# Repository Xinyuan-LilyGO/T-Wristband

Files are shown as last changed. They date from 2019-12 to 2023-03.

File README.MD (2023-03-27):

<h1 align = "center">🌟LilyGo T-Wristband🌟</h1>

**NOTE**

- [Better bracelet application from yacubovvs/CubOS](https://github.com/yacubovvs/CubOS)

- The new version screen (green label) requires configuration changes. [Refer to section 3 of this document for configuration](examples/T-Wristband-MPU9250/README.MD)

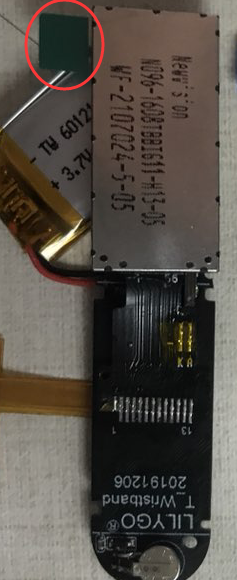
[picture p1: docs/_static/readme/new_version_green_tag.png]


- T-Wristband has two types of sensors, LSM9DS1 and MPU9250 sensors. How to distinguish the version you bought, please see the upper right part of the board below to distinguish

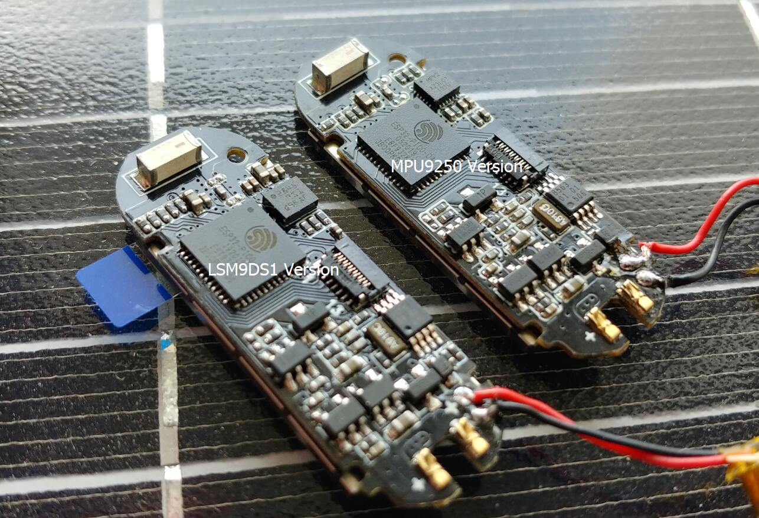
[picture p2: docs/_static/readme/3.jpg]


## Documentation

You can use the [T-Wristband Online Documentation](https://t-wristband-zh-cn.readthedocs.io/en/latest) to get all information about this project.

* [Getting Started](https://t-wristband-zh-cn.readthedocs.io/en/latest/get-started/index.html)
* [Hardware Reference](https://docs.espressif.com/projects/arduino-esp32/en/latest/installing.html)
* [Examples](https://t-wristband-zh-cn.readthedocs.io/en/latest/soft-reference/index.html)
* [Troubleshooting](https://t-wristband-zh-cn.readthedocs.io/en/latest/troubleshooting.html)
* [Copyrights](https://t-wristband-zh-cn.readthedocs.io/en/latest/COPYRIGHT.html)

## 📷 Product

| Examples | Product  Link | Schematic | Status |
| :---: | :---: | :---: | :----: |
| [LSM9DS1 Version](examples/T-Wristband-LSM9DS1/README_CN.md) | [AliExpress](https://www.aliexpress.com/item/4001162589218.html) | [Schematic](./schematic/T_Wristband_lsm9ds1_20200306.pdf) | ✅ |
| [MPU9250 Version](examples/T-Wristband-MPU9250/README_CN.md) | [AliExpress](https://www.aliexpress.com/item/4001162589218.html) | [Schematic](./schematic/T_Wristband_mpu9250.pdf) | ✅ |
| [MAX3010X](examples/T-Wristband-MAX3010X/README_CN.md) | [AliExpress](https://www.aliexpress.com/item/3256801677444772.html) | [Schematic](./schematic/T_Wristband_MAX30102.pdf) | ✅ |
| [DRV2605](examples/T-Wristband-DRV2605/README_CN.md) | [AliExpress](https://www.aliexpress.com/item/3256801703960897.html) | [Schematic](./schematic/T_Wristband_DRV2605.pdf) | ✅ |

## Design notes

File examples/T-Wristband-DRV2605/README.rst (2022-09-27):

*********
DRV2605
*********

.. note::

    Before using it, please install :ref:`Get Started <Install dependent libraries>`.

Introduction
=============

This document is `T-Wristband-DRV2605 <https://github.com/Xinyuan-LilyGO/LilyGo-T-Wristband/tree/master/examples/T-Wristband-DRV2605>`_ example description. DRV2605 Haptic Module for instructing the user how to use the ``T-Wristband``.

Arduino
========

``T-Wristband`` can choose ``ESP32 Dev Module``, and other settings can be kept as default.

.. warning::

    ``T-Wristband`` does not use PSRAM, please do not enable PSRAM, and call PSRAM functions.

For more DRV2605 examples, please refer to `Adafruit_DRV2605_Library <https://github.com/adafruit/Adafruit_DRV2605_Library>`_ .

Related Function Switch
========================

Some functions can be enabled or disabled by modifying the relevant macros in |l_github_Wristband-DRV2605.ino|_.

DRV2605 Haptic Module
----------------------

The ``ENABLE_DRV2605`` macro is used to enable the DRV2605 haptic module and is enabled by default.

.. literalinclude:: ../../../examples/T-Wristband-DRV2605/T-Wristband-DRV2605.ino
    :linenos:
    :language: c
    :lines: 13-13
    :lineno-start: 13

Hardware Test
---------------

The ``FACTORY_HW_TEST`` macro is used to test whether the hardware status of the bracelet is normal. It is disabled by default.

.. literalinclude:: ../../../examples/T-Wristband-DRV2605/T-Wristband-DRV2605.ino
    :linenos:
    :language: c
    :lines: 14-14
    :lineno-start: 14

OTA update
-----------

The ``ARDUINO_OTA_UPDATE`` macro is used to enable the OTA update function, which is disabled by default.

.. literalinclude:: ../../../examples/T-Wristband-DRV2605/T-Wristband-DRV2605.ino
    :linenos:
    :language: c
    :lines: 15-15
    :lineno-start: 15

.. _l_github_Wristband-DRV2605.ino: https://github.com/Xinyuan-LilyGO/LilyGo-T-Wristband/tree/master/examples/T-Wristband-DRV2605/T-Wristband-DRV2605.ino
.. |l_github_Wristband-DRV2605.ino| replace:: T-Wristband-DRV2605.ino

User Manual
============

OTA update:

    1. Touch and hold the button for three seconds to do a ``WiFi`` reset.
    #. Select ``T-Wristband`` in the ``Arduino IDE`` port to upgrade over the air, as shown below:

        

.. note::

    Enable ``ARDUINO_OTA_UPDATE`` macro OTA update is valid.

Datasheet
==========

* `ESP32-PICO-D4`_ (Datasheet)
* `ST7735`_ (Datasheet)
* `DRV2605`_ (Datasheet)

.. _ESP32-PICO-D4: https://www.espressif.com.cn/sites/default/files/documentation/esp32-pico-d4_datasheet_en.pdf
.. _ST7735: http://www.displayfuture.com/Display/datasheet/controller/ST7735.pdf
.. _DRV2605: https://www.ti.com/lit/ds/symlink/drv2605.pdf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

Pinout
===========

======== ====
Name     Pin
-------- ----
DRV_SDA  15
-------- ----
DRV_SCL  13
======== ====

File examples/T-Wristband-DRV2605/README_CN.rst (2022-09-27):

*********
DRV2605
*********

.. note::

    使用之前，请先安装 :ref:`快速开始 <安装依赖库>` 。

概况
======

本文档是 `T-Wristband-DRV2605 <https://github.com/Xinyuan-LilyGO/LilyGo-T-Wristband/tree/master/examples/T-Wristband-DRV2605>`_ 示例说明。用于指导用户如何使用 ``T-Wristband`` 的 DRV2605 触觉模块。

Arduino
========

板子可以选择 ``ESP32 Dev Module``，其他设置可以保持默认。

.. warning::

    ``T-Wristband`` 没有使用 PSRAM，请勿开启 PSRAM，和调用 PSRAM 的功能函数。

更多心率示例请参考 `Adafruit_DRV2605_Library <https://github.com/adafruit/Adafruit_DRV2605_Library>`_ 。

相关功能开关
============

通过修改 `T-Wristband-DRV2605.ino <https://github.com/Xinyuan-LilyGO/LilyGo-T-Wristband/tree/master/examples/T-Wristband-DRV2605/T-Wristband-DRV2605.ino>`_ 中的相关宏，使能或者失能某些功能。

DRV2605 触觉模块
----------------------

``ENABLE_DRV2605`` 宏用于使能 DRV2605 触觉模块，默认打开。

.. literalinclude:: ../../../examples/T-Wristband-DRV2605/T-Wristband-DRV2605.ino
    :linenos:
    :language: c
    :lines: 13-13
    :lineno-start: 13

测试手环的硬件状态是否正常
-----------------------------

``FACTORY_HW_TEST`` 宏用于测试手环的硬件状态是否正常，默认关闭。

.. literalinclude:: ../../../examples/T-Wristband-DRV2605/T-Wristband-DRV2605.ino
    :linenos:
    :language: c
    :lines: 14-14
    :lineno-start: 14

OTA 更新
---------

``ARDUINO_OTA_UPDATE`` 宏用于开启 OTA 更新功能，默认关闭。

.. literalinclude:: ../../../examples/T-Wristband-DRV2605/T-Wristband-DRV2605.ino
    :linenos:
    :language: c
    :lines: 15-15
    :lineno-start: 15

使用说明
=========

OTA 更新:

    1. 触摸按住按钮三秒钟，进行 ``WiFi`` 重置。
    #. 在 ``Arduino IDE`` 端口中选择 ``T-Wristband`` 进行空中升级，如下图：

        

.. note::

    使能 ``ARDUINO_OTA_UPDATE`` 宏 OTA 更新才有效。

数据手册
=========

* `ESP32-PICO-D4`_ (Datasheet)
* `ST7735`_ (Datasheet)
* `DRV2605`_ (Datasheet)

.. _ESP32-PICO-D4: https://www.espressif.com.cn/sites/default/files/documentation/esp32-pico-d4_datasheet_cn.pdf
.. _ST7735: http://www.displayfuture.com/Display/datasheet/controller/ST7735.pdf
.. _DRV2605: https://www.ti.com/lit/ds/symlink/drv2605.pdf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

引脚定义
========

======== ====
Name     Pin
-------- ----
DRV_SDA  15
-------- ----
DRV_SCL  13
======== ====

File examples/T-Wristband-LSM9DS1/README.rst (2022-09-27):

*********
LSM9DS1
*********

.. note::

    Before using it, please install :ref:`Get Started <Install dependent libraries>`.

Introduction
=============

This document is `T-Wristband-LSM9DS1 <https://github.com/Xinyuan-LilyGO/LilyGo-T-Wristband/tree/master/examples/T-Wristband-LSM9DS1>`_ example description. LSM9DS1 sensor for instructing the user how to use the ``T-Wristband``.

Arduino
========

``T-Wristband`` can choose ``ESP32 Dev Module``, and other settings can be kept as default.

.. warning::

    ``T-Wristband`` does not use PSRAM, please do not enable PSRAM, and call PSRAM functions.

Related Function Switch
========================

By modifying `T-Wristband-LSM9DS1.ino <https://github.com/Xinyuan-LilyGO/LilyGo-T-Wristband/tree/master/examples/T-Wristband-LSM9DS1/T-Wristband-LSM9DS1.ino>`_ The related macros in _ enable or disable certain functions.

Hardware Test
---------------

The ``FACTORY_HW_TEST`` macro is used to test whether the hardware status of the bracelet is normal. It is disabled by default.

.. literalinclude:: ../../../examples/T-Wristband-LSM9DS1/T-Wristband-LSM9DS1.ino
    :linenos:
    :language: c
    :lines: 14-14
    :lineno-start: 14

BLE transmits IMU data
-----------------------

The ``ENABLE_BLE_DATA_TRANSMISSION`` macro is used to test the BLE transfer IMU data example, which is disabled by default.

You can use ``nRF Connect``, ``LightBlue`` and other APPs to connect to view the data.

.. literalinclude:: ../../../examples/T-Wristband-LSM9DS1/T-Wristband-LSM9DS1.ino
    :linenos:
    :language: c
    :lines: 20-20
    :lineno-start: 20

Enable LSM9DS1 sensor function
-------------------------------

The ``ENABLE_SENSOR`` macro is used to enable the LSM9DS1 sensor function. Off by default.

.. literalinclude:: ../../../examples/T-Wristband-LSM9DS1/T-Wristband-LSM9DS1.ino
    :linenos:
    :language: c
    :lines: 23-23
    :lineno-start: 23

Enable LSM9DS1 sensor shutdown mode function
---------------------------------------------

The ``USE_PROTECTED_MEMBERS`` macro is used to enable the LSM9DS1 sensor shutdown mode function. Off by default.

.. literalinclude:: ../../../examples/T-Wristband-LSM9DS1/T-Wristband-LSM9DS1.ino
    :linenos:
    :language: c
    :lines: 37-37
    :lineno-start: 37

.. note::

    Before use, please make sure that you have changed the three member methods of SparkFun_LSM9DS1_Arduino_Library to common member methods, or directly use the library file in `libdeps`.

OTA update
-----------

The ``ARDUINO_OTA_UPDATE`` macro is used to enable the OTA update function, which is disabled by default.

.. literalinclude:: ../../../examples/T-Wristband-LSM9DS1/T-Wristband-LSM9DS1.ino
    :linenos:
    :language: c
    :lines: 17-17
    :lineno-start: 17

User Manual
============

Touch the button to switch to the next function when a press is detected:

    1. Press for the first time to view the nine-axis sensor information
    #. Press it a second time to enter deep sleep
    #. During deep sleep, touch again to wake up the bracelet

OTA update:

    1. Touch and hold the button for three seconds to do a ``WiFi`` reset.
    #. Select ``T-Wristband`` in the ``Arduino IDE`` port to upgrade over the air, as shown below:

        

.. note::

    Enable ``ARDUINO_OTA_UPDATE`` macro OTA update is valid.

Datasheet
==========

* `ESP32-PICO-D4`_ (Datasheet)
* `ST7735`_ (Datasheet)
* `LSM9DS1`_ (Datasheet)

.. _ESP32-PICO-D4: https://www.espressif.com.cn/sites/default/files/documentation/esp32-pico-d4_datasheet_en.pdf
.. _ST7735: http://www.displayfuture.com/Display/datasheet/controller/ST7735.pdf
.. _LSM9DS1: https://www.st.com/resource/en/datasheet/lsm9ds1.pdf

Pinout
===========

================== ======
Name               Pin
------------------ ------
TFT Driver         ST7735
TFT_MISO           N/A   
TFT_MOSI           19    
TFT_SCLK           18    
TFT_CS             5     
TFT_DC             23    
TFT_RST            26    
TFT_BL             27    
Touchpad           33    
Touchpad Power     25    
RTC Interrupt      34    
Battery ADC        35    
I2C_SDA            21    
I2C_SCL            22    
CHARGE Indication  32    
IMU INT1           38    
IMU INT2           39    
IMU INTM           37    
IMU RDY            36    
================== ======

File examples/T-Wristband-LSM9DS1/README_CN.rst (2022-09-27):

*********
LSM9DS1
*********

.. note::

    使用之前，请先安装 :ref:`快速开始 <安装依赖库>` 。

概况
======

本文档是 `T-Wristband-LSM9DS1 <https://github.com/Xinyuan-LilyGO/LilyGo-T-Wristband/tree/master/examples/T-Wristband-LSM9DS1>`_ 示例说明。用于指导用户如何使用 ``T-Wristband`` 的 LSM9DS1 传感器。

Arduino
========

板子可以选择 ``ESP32 Dev Module``，其他设置可以保持默认。

.. warning::

    ``T-Wristband`` 没有使用 PSRAM，请勿开启 PSRAM，和调用 PSRAM 的功能函数。

相关功能开关
============

通过修改 `T-Wristband-LSM9DS1.ino <https://github.com/Xinyuan-LilyGO/LilyGo-T-Wristband/tree/master/examples/T-Wristband-LSM9DS1/T-Wristband-LSM9DS1.ino>`_ 中的相关宏，使能或者失能某些功能。

测试手环的硬件状态是否正常
-----------------------------

``FACTORY_HW_TEST`` 宏用于测试手环的硬件状态是否正常，默认关闭。

.. literalinclude:: ../../../examples/T-Wristband-LSM9DS1/T-Wristband-LSM9DS1.ino
    :linenos:
    :language: c
    :lines: 14-14
    :lineno-start: 14

测试 BLE 传输 IMU 数据
-----------------------

``ENABLE_BLE_DATA_TRANSMISSION`` 宏用于测试BLE传输IMU数据示例，默认关闭。

可以使用 ``nRF Connect``， ``LightBlue`` 等 APP 进行连接查看数据。

.. literalinclude:: ../../../examples/T-Wristband-LSM9DS1/T-Wristband-LSM9DS1.ino
    :linenos:
    :language: c
    :lines: 20-20
    :lineno-start: 20

开启 LSM9DS1 传感器功能
-----------------------

``ENABLE_SENSOR`` 宏用于开启 LSM9DS1 传感器功能。默认关闭。

.. literalinclude:: ../../../examples/T-Wristband-LSM9DS1/T-Wristband-LSM9DS1.ino
    :linenos:
    :language: c
    :lines: 23-23
    :lineno-start: 23

开启 LSM9DS1 传感器关断模式功能
-------------------------------

``USE_PROTECTED_MEMBERS`` 宏用于开启 LSM9DS1 传感器关断模式功能。默认关闭。

.. literalinclude:: ../../../examples/T-Wristband-LSM9DS1/T-Wristband-LSM9DS1.ino
    :linenos:
    :language: c
    :lines: 37-37
    :lineno-start: 37

.. note::

    使用前请确保你已经将 SparkFun_LSM9DS1_Arduino_Library 三个成员方法更改为共有成员方法，或者直接使用 `libdeps` 内的库文件。

OTA 更新
---------

``ARDUINO_OTA_UPDATE`` 宏用于开启 OTA 更新功能，默认关闭。

.. literalinclude:: ../../../examples/T-Wristband-LSM9DS1/T-Wristband-LSM9DS1.ino
    :linenos:
    :language: c
    :lines: 17-17
    :lineno-start: 17

使用说明
=========

触摸按钮当检测到按下则切换功能:

    1. 按下第一次 将查看九轴传感器信息
    #. 按下第二次 将进入深度睡眠
    #. 在深度睡眠中，再次触摸唤醒手环

OTA 更新:

    1. 触摸按住按钮三秒钟，进行 ``WiFi`` 重置。
    #. 在 ``Arduino IDE`` 端口中选择 ``T-Wristband`` 进行空中升级，如下图：

        

.. note::

    使能 ``ARDUINO_OTA_UPDATE`` 宏 OTA 更新才有效。

数据手册
=========

* `ESP32-PICO-D4`_ (Datasheet)
* `ST7735`_ (Datasheet)
* `LSM9DS1`_ (Datasheet)

.. _ESP32-PICO-D4: https://www.espressif.com.cn/sites/default/files/documentation/esp32-pico-d4_datasheet_cn.pdf
.. _ST7735: http://www.displayfuture.com/Display/datasheet/controller/ST7735.pdf
.. _LSM9DS1: https://www.st.com/resource/en/datasheet/lsm9ds1.pdf

引脚定义
========

================== ======
Name               Pin
------------------ ------
TFT Driver         ST7735
TFT_MISO           N/A   
TFT_MOSI           19    
TFT_SCLK           18    
TFT_CS             5     
TFT_DC             23    
TFT_RST            26    
TFT_BL             27    
Touchpad           33    
Touchpad Power     25    
RTC Interrupt      34    
Battery ADC        35    
I2C_SDA            21    
I2C_SCL            22    
CHARGE Indication  32    
IMU INT1           38    
IMU INT2           39    
IMU INTM           37    
IMU RDY            36    
================== ======

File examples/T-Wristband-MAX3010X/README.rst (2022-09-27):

*********
MAX3010X
*********

.. note::

    Before using it, please install :ref:`Get Started <Install dependent libraries>`.

Introduction
=============

This document is `T-Wristband-MAX3010X <https://github.com/Xinyuan-LilyGO/LilyGo-T-Wristband/tree/master/examples/T-Wristband-MAX3010X>`_ example description. A MAX3010X sensor for instructing the user on how to use the ``T-Wristband``.

Arduino
========

``T-Wristband`` can choose ``ESP32 Dev Module``, and other settings can be kept as default.

For more heart rate examples, please refer to `SparkFun_MAX3010x_Sensor_Library <https://github.com/sparkfun/SparkFun_MAX3010x_Sensor_Library>`_ .

.. warning::

    ``T-Wristband`` does not use PSRAM, please do not enable PSRAM, and call PSRAM functions.

Datasheet
==========

* `ESP32-PICO-D4`_ (Datasheet)
* `ST7735`_ (Datasheet)
* `MAX30102`_ (Datasheet)

.. _ESP32-PICO-D4: https://www.espressif.com.cn/sites/default/files/documentation/esp32-pico-d4_datasheet_en.pdf
.. _ST7735: http://www.displayfuture.com/Display/datasheet/controller/ST7735.pdf
.. _MAX30102: https://datasheets.maximintegrated.com/en/ds/MAX30102.pdf

Pinout
===========

============= ====
Name          Pin
------------- ----
MAX3010X_SDA  15
------------- ----
MAX3010X_SCL  13
------------- ----
MAX3010X_IRQ  4
============= ====

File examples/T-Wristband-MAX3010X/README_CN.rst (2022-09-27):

*********
MAX3010X
*********

.. note::

    使用之前，请先安装 :ref:`快速开始 <安装依赖库>` 。

概况
======

本文档是 `T-Wristband-MAX3010X <https://github.com/Xinyuan-LilyGO/LilyGo-T-Wristband/tree/master/examples/T-Wristband-MAX3010X>`_ 示例说明。用于指导用户如何使用 ``T-Wristband`` 的 MAX3010X 传感器。

Arduino
========

板子可以选择 ``ESP32 Dev Module``，其他设置可以保持默认。

.. warning::

    ``T-Wristband`` 没有使用 PSRAM，请勿开启 PSRAM，和调用 PSRAM 的功能函数。

更多心率示例请参考 `SparkFun_MAX3010x_Sensor_Library <https://github.com/sparkfun/SparkFun_MAX3010x_Sensor_Library>`_ 。

数据手册
=========

* `ESP32-PICO-D4`_ (Datasheet)
* `ST7735`_ (Datasheet)
* `MAX30102`_ (Datasheet)

.. _ESP32-PICO-D4: https://www.espressif.com.cn/sites/default/files/documentation/esp32-pico-d4_datasheet_cn.pdf
.. _ST7735: http://www.displayfuture.com/Display/datasheet/controller/ST7735.pdf
.. _MAX30102: https://datasheets.maximintegrated.com/en/ds/MAX30102.pdf

引脚定义
========

============= ====
Name          Pin
------------- ----
MAX3010X_SDA  15
------------- ----
MAX3010X_SCL  13
------------- ----
MAX3010X_IRQ  4
============= ====

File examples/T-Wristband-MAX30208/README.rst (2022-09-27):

*********
MAX30208
*********

.. note::

    Before using it, please install :ref:`Get Started <Install dependent libraries>`.

Introduction
=============

This document is a `T-Wristband-MAX30208 <https://github.com/Xinyuan-LilyGO/LilyGo-T-Wristband/tree/master/examples/T-Wristband-MAX30208>`_ example description. A MAX30208 sensor for instructing the user on how to use the ``T-Wristband``.

Arduino
========

``T-Wristband`` can choose ``ESP32 Dev Module``, and other settings can be kept as default.

.. warning::

    ``T-Wristband`` does not use PSRAM, please do not enable PSRAM, and call PSRAM functions.

Related Function Switch
========================

By modifying `T-Wristband-MAX30208.ino <https://github.com/Xinyuan-LilyGO/LilyGo-T-Wristband/tree/master/examples/T-Wristband-MAX30208/T-Wristband-MAX30208.ino>`_ The related macros in _ enable or disable certain functions.

Hardware Test
---------------

The ``FACTORY_HW_TEST`` macro is used to test whether the hardware status of the bracelet is normal. It is disabled by default.

.. literalinclude:: ../../../examples/T-Wristband-MAX30208/T-Wristband-MAX30208.ino
    :linenos:
    :language: c
    :lines: 16-16
    :lineno-start: 16

OTA update
-----------

The ``ARDUINO_OTA_UPDATE`` macro is used to enable the OTA update function, which is disabled by default.

.. literalinclude:: ../../../examples/T-Wristband-MAX30208/T-Wristband-MAX30208.ino
    :linenos:
    :language: c
    :lines: 17-17
    :lineno-start: 17

.. _l_github_Wristband-MPU9250.ino: https://github.com/Xinyuan-LilyGO/LilyGo-T-Wristband/tree/master/examples/T-Wristband-MAX30208/T-Wristband-MAX30208.ino
.. |l_github_Wristband-MPU9250.ino| replace:: T-Wristband-MAX30208.ino

User Manual
============

OTA update:

    1. Touch and hold the button for three seconds to do a ``WiFi`` reset.
    #. Select ``T-Wristband`` in the ``Arduino IDE`` port to upgrade over the air, as shown below:

        

.. note::

    Enable ``ARDUINO_OTA_UPDATE`` macro OTA update is valid.

Datasheet
==========

* `ESP32-PICO-D4`_ (Datasheet)
* `ST7735`_ (Datasheet)
* `MAX30208`_ (Datasheet)

.. _ESP32-PICO-D4: https://www.espressif.com.cn/sites/default/files/documentation/esp32-pico-d4_datasheet_en.pdf
.. _ST7735: http://www.displayfuture.com/Display/datasheet/controller/ST7735.pdf
.. _MAX30208: https://datasheets.maximintegrated.com/en/ds/MAX30208.pdf

Pinout
===========

======== ====
Name     Pin
-------- ----
DRV_SDA  15
-------- ----
DRV_SCL  13
======== ====

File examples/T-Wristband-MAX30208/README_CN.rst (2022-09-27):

*********
MAX30208
*********

.. note::

    使用之前，请先安装 :ref:`快速开始 <安装依赖库>` 。

概况
======

本文档是 `T-Wristband-MAX30208 <https://github.com/Xinyuan-LilyGO/LilyGo-T-Wristband/tree/master/examples/T-Wristband-MAX30208>`_ 示例说明。用于指导用户如何使用 ``T-Wristband`` 的 MAX30208 传感器。

Arduino
========

板子可以选择 ``ESP32 Dev Module``，其他设置可以保持默认。

.. warning::

    ``T-Wristband`` 没有使用 PSRAM，请勿开启 PSRAM，和调用 PSRAM 的功能函数。

相关功能开关
============

通过修改 `T-Wristband-MAX30208.ino <https://github.com/Xinyuan-LilyGO/LilyGo-T-Wristband/tree/master/examples/T-Wristband-MAX30208/T-Wristband-MAX30208.ino>`_ 中的相关宏，使能或者失能某些功能。

测试手环的硬件状态是否正常
--------------------------

``FACTORY_HW_TEST`` 宏用于测试手环的硬件状态是否正常，默认关闭。

.. literalinclude:: ../../../examples/T-Wristband-MAX30208/T-Wristband-MAX30208.ino
    :linenos:
    :language: c
    :lines: 16-16
    :lineno-start: 16

启用 OTA 更新
--------------

``ARDUINO_OTA_UPDATE`` 宏用于开启 OTA 更新功能，默认关闭。

.. literalinclude:: ../../../examples/T-Wristband-MAX30208/T-Wristband-MAX30208.ino
    :linenos:
    :language: c
    :lines: 17-17
    :lineno-start: 17

.. _l_github_Wristband-MPU9250.ino: https://github.com/Xinyuan-LilyGO/LilyGo-T-Wristband/tree/master/examples/T-Wristband-MAX30208/T-Wristband-MAX30208.ino
.. |l_github_Wristband-MPU9250.ino| replace:: T-Wristband-MAX30208.ino

使用说明
=========

OTA 更新:

    1. 触摸按住按钮三秒钟，进行 ``WiFi`` 重置。
    #. 在 ``Arduino IDE`` 端口中选择 ``T-Wristband`` 进行空中升级，如下图：

        

.. note::

    使能 ``ARDUINO_OTA_UPDATE`` 宏 OTA 更新才有效。

数据手册
=========

* `ESP32-PICO-D4`_ (Datasheet)
* `ST7735`_ (Datasheet)
* `MAX30208`_ (Datasheet)

.. _ESP32-PICO-D4: https://www.espressif.com.cn/sites/default/files/documentation/esp32-pico-d4_datasheet_cn.pdf
.. _ST7735: http://www.displayfuture.com/Display/datasheet/controller/ST7735.pdf
.. _MAX30208: https://datasheets.maximintegrated.com/en/ds/MAX30208.pdf

引脚定义
========

======== ====
Name     Pin
-------- ----
DRV_SDA  15
-------- ----
DRV_SCL  13
======== ====

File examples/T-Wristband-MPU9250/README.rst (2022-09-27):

*********
MPU9250
*********

.. note::

    Before using it, please install :ref:`Get Started <Install dependent libraries>`.

Introduction
=============

This document is `T-Wristband-MPU9250 <https://github.com/Xinyuan-LilyGO/LilyGo-T-Wristband/tree/master/examples/T-Wristband-MPU9250>`_ example description. MPU9250 sensor for instructing the user how to use the ``T-Wristband``.

Arduino
========

``T-Wristband`` can choose ``ESP32 Dev Module``, and other settings can be kept as default.

.. warning::

    ``T-Wristband`` does not use PSRAM, please do not enable PSRAM, and call PSRAM functions.

Related Function Switch
========================

Enable or disable certain functions by modifying the relevant macros in |l_github_Wristband-MPU9250.ino|_.

Hardware Test
---------------

The ``FACTORY_HW_TEST`` macro is used to test whether the hardware status of the bracelet is normal. It is disabled by default.

.. literalinclude:: ../../../examples/T-Wristband-MPU9250/T-Wristband-MPU9250.ino
    :linenos:
    :language: c
    :lines: 14-14
    :lineno-start: 14

OTA update
-----------

The ``ARDUINO_OTA_UPDATE`` macro is used to enable the OTA update function, which is disabled by default.

.. literalinclude:: ../../../examples/T-Wristband-MPU9250/T-Wristband-MPU9250.ino
    :linenos:
    :language: c
    :lines: 17-17
    :lineno-start: 17

.. _l_github_Wristband-MPU9250.ino: https://github.com/Xinyuan-LilyGO/LilyGo-T-Wristband/tree/master/examples/T-Wristband-MPU9250/T-Wristband-MPU9250.ino
.. |l_github_Wristband-MPU9250.ino| replace:: T-Wristband-MPU9250.ino

User Manual
============

Touch the button to switch to the next function when a press is detected:

    1. Press for the first time to view the nine-axis sensor information
    #. Press it a second time to enter deep sleep
    #. During deep sleep, touch again to wake up the bracelet

OTA update:

    1. Touch and hold the button for three seconds to do a ``WiFi`` reset.
    #. Select ``T-Wristband`` in the ``Arduino IDE`` port to upgrade over the air, as shown below:

        

.. note::

    Enable ``ARDUINO_OTA_UPDATE`` macro OTA update is valid.

Datasheet
==========

* `ESP32-PICO-D4`_ (Datasheet)
* `ST7735`_ (Datasheet)
* `MPU9250`_ (Datasheet)

.. _ESP32-PICO-D4: https://www.espressif.com.cn/sites/default/files/documentation/esp32-pico-d4_datasheet_en.pdf
.. _ST7735: http://www.displayfuture.com/Display/datasheet/controller/ST7735.pdf
.. _MPU9250: https://invensense.tdk.com/wp-content/uploads/2015/02/PS-MPU-9250A-01-v1.1.pdf

Pinout
===========

================== =======
Name               Pin
------------------ -------
TFT Driver         ST7735
TFT_MISO           N/A
TFT_MOSI           19
TFT_SCLK           18
TFT_CS             5
TFT_DC             23
TFT_RST            26
TFT_BL             27
Touchpad           33
Touchpad Power     25
IMU Interrupt      38
RTC Interrupt      34
Battery ADC        35
VBUS ADC           36
I2C SDA            21
I2C SCL            22
LED and Vibration  4
CHARGE Indication  38
================== =======

.. note::

    The vibration module is driven using IO4, which is incorporated with the LED.

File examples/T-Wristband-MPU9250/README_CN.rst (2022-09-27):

*********
MPU9250
*********

.. note::

    使用之前，请先安装 :ref:`快速开始 <安装依赖库>` 。

概况
======

本文档是 `T-Wristband-MPU9250 <https://github.com/Xinyuan-LilyGO/LilyGo-T-Wristband/tree/master/examples/T-Wristband-MPU9250>`_ 示例说明。用于指导用户如何使用 ``T-Wristband`` 的 MPU9250 传感器。

Arduino
========

板子可以选择 ``ESP32 Dev Module``，其他设置可以保持默认。

.. warning::

    ``T-Wristband`` 没有使用 PSRAM，请勿开启 PSRAM，和调用 PSRAM 的功能函数。

相关功能开关
============

通过修改 |l_github_Wristband-MPU9250.ino|_ 中的相关宏，使能或者失能某些功能。

测试手环的硬件状态是否正常
--------------------------

``FACTORY_HW_TEST`` 宏用于测试手环的硬件状态是否正常，默认关闭。

.. literalinclude:: ../../../examples/T-Wristband-MPU9250/T-Wristband-MPU9250.ino
    :linenos:
    :language: c
    :lines: 14-14
    :lineno-start: 14

启用 OTA 更新
--------------

``ARDUINO_OTA_UPDATE`` 宏用于开启 OTA 更新功能，默认关闭。

.. literalinclude:: ../../../examples/T-Wristband-MPU9250/T-Wristband-MPU9250.ino
    :linenos:
    :language: c
    :lines: 17-17
    :lineno-start: 17

.. _l_github_Wristband-MPU9250.ino: https://github.com/Xinyuan-LilyGO/LilyGo-T-Wristband/tree/master/examples/T-Wristband-MPU9250/T-Wristband-MPU9250.ino
.. |l_github_Wristband-MPU9250.ino| replace:: T-Wristband-MPU9250.ino

使用说明
=========

触摸按钮当检测到按下则切换功能:

    1. 按下第一次 将查看九轴传感器信息
    #. 按下第二次 将进入深度睡眠
    #. 在深度睡眠中，再次触摸唤醒手环

OTA 更新:

    1. 触摸按住按钮三秒钟，进行 ``WiFi`` 重置。
    #. 在 ``Arduino IDE`` 端口中选择 ``T-Wristband`` 进行空中升级，如下图：

        

.. note::

    使能 ``ARDUINO_OTA_UPDATE`` 宏 OTA 更新才有效。

数据手册
=========

* `ESP32-PICO-D4`_ (Datasheet)
* `ST7735`_ (Datasheet)
* `MPU9250`_ (Datasheet)

.. _ESP32-PICO-D4: https://www.espressif.com.cn/sites/default/files/documentation/esp32-pico-d4_datasheet_cn.pdf
.. _ST7735: http://www.displayfuture.com/Display/datasheet/controller/ST7735.pdf
.. _MPU9250: https://invensense.tdk.com/wp-content/uploads/2015/02/PS-MPU-9250A-01-v1.1.pdf

引脚定义
========

================== =======
Name               Pin
------------------ -------
TFT Driver         ST7735
TFT_MISO           N/A
TFT_MOSI           19
TFT_SCLK           18
TFT_CS             5
TFT_DC             23
TFT_RST            26
TFT_BL             27
Touchpad           33
Touchpad Power     25
IMU Interrupt      38
RTC Interrupt      34
Battery ADC        35
VBUS ADC           36
I2C SDA            21
I2C SCL            22
LED and Vibration  4
CHARGE Indication  38
================== =======

.. note::

    振动模块使用IO4进行驱动，与 LED 合并在一起。

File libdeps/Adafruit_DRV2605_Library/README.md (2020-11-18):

# Adafruit DRV2605 Library 

This is a library for the Adafruit DRV2605L Haptic Driver ----> http://www.adafruit.com/products/2305

Check out the links above for our tutorials and wiring diagrams.

This motor/haptic driver uses I2C to communicate.

Adafruit invests time and resources providing this open source code,
please support Adafruit and open-source hardware by purchasing
products from Adafruit!

Written by Limor Fried/Ladyada for Adafruit Industries.

MIT license, all text above must be included in any redistribution.

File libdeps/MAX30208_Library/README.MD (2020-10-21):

MAX30208 Sensor Library
=====================

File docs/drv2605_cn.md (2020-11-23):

## **[English](../examples/T-Wristband-DRV2605/README.MD) | 中文**

## 使用之前,请阅读下面的描述

1. 根据你使用的串口通讯板安装对应的驱动程序
   - [CP21xx Drivers](https://www.silabs.com/products/development-tools/software/usb-to-uart-bridge-vcp-drivers)
   - [CH340 Drivers](http://www.wch-ic.com/search?q=ch340&t=downloads)

2. 安装下面列表中的依赖库,默认已将所需要的库文件放置在`libdeps`目录中,请将`libdeps`目录内所有文件拷贝到`C:\<UserName>\Documents\Arduino\libraries`目录内
   - [TFT_eSPI](https://github.com/Bodmer/TFT_eSPI)
   - [Adafruit_DRV2605_Library](https://github.com/adafruit/Adafruit_DRV2605_Library)

3. 配置TFT头文件(**如果使用`libdeps`目录中库文件,可以跳过这一步**)
    - 在你的库文件夹目录中找到**TFT_eSPI**目录
    - 在**TFT_eSPI**根目录中找到`User_Setup_Select.h`并且打开进行编辑
    - 将 文件头部`#include <User_Setup.h>` 注释掉
    - 找到 `#include <User_Setups/Setup26_TTGO_T_Wristband.h>`,取消前面的注释,保存退出
    - 最终效果如下图:
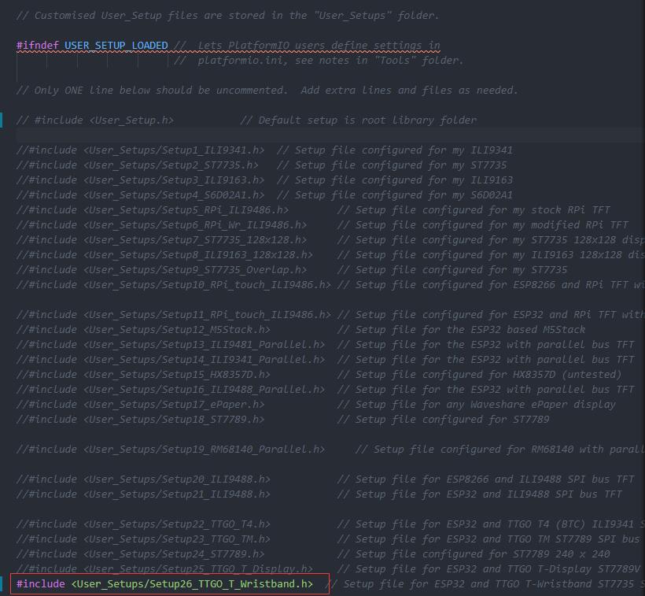
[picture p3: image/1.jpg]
        
4. 板子可以选择**ESP32 Dev Module**，其他设置可以保持默认,注意 `T-Wristband` 没有使用PSRAM,请勿开启PSRAM,和调用PSRAM的功能函数

5. 更多心率示例请参考`Adafruit_DRV2605_Library`

## 数据手册
- [DRV2605](https://www.ti.com/product/DRV2605)
- [ST7735](http://www.displayfuture.com/Display/datasheet/controller/ST7735.pdf)
- [ESP32-PICO-D4](https://www.espressif.com/sites/default/files/documentation/esp32-pico-d4_datasheet_en.pdf)

## 引脚定义
| Name | Pin |
| --- | --- |
| DRV_SDA | 15  |
| DRV_SCL | 13  |

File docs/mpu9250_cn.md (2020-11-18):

## **[English](../examples/T-Wristband-MPU9250/README.MD) | 中文**

## 使用之前,请阅读下面的描述

1. 根据你使用的串口通讯板安装对应的驱动程序
   - [CP21xx Drivers](https://www.silabs.com/products/development-tools/software/usb-to-uart-bridge-vcp-drivers)
   - [CH340 Drivers](http://www.wch-ic.com/search?q=ch340&t=downloads)

2. 安装下面列表中的依赖库,默认已将所需要的库文件放置在`libdeps`目录中,请将`libdeps`目录内所有文件拷贝到`C:\<UserName>\Documents\Arduino\libraries`目录内
   - [TFT_eSPI](https://github.com/Bodmer/TFT_eSPI)
   - [PCF8563_Library](https://github.com/lewisxhe/PCF8563_Library)

3. 配置TFT头文件(**如果使用`libdeps`目录中库文件,可以跳过这一步**)
    - 在你的库文件夹目录中找到**TFT_eSPI**目录
    - 在**TFT_eSPI**根目录中找到`User_Setup_Select.h`并且打开进行编辑
    - 将 文件头部`#include <User_Setup.h>` 注释掉
    - 找到 `#include <User_Setups/Setup26_TTGO_T_Wristband.h>`,取消前面的注释,保存退出
    - 最终效果如下图:
        
4. 板子可以选择**ESP32 Dev Module**，其他设置可以保持默认,注意 `T-Wristband` 没有使用PSRAM,请勿开启PSRAM,和调用PSRAM的功能函数

5. `ARDUINO_OTA_UPDATE` 宏用于**WiFiManager**和**OTA更新**,默认为关闭,如需开启请在`sketch`中开启
    - 当`ARDUINO_OTA_UPDATE`开启后,触摸按住按钮三秒钟进行`WiFi`重置
    - 开启OTA更新后,你可以在Arduino IDE端口中选择 `T-Wristband` 进行空中升级,如下图
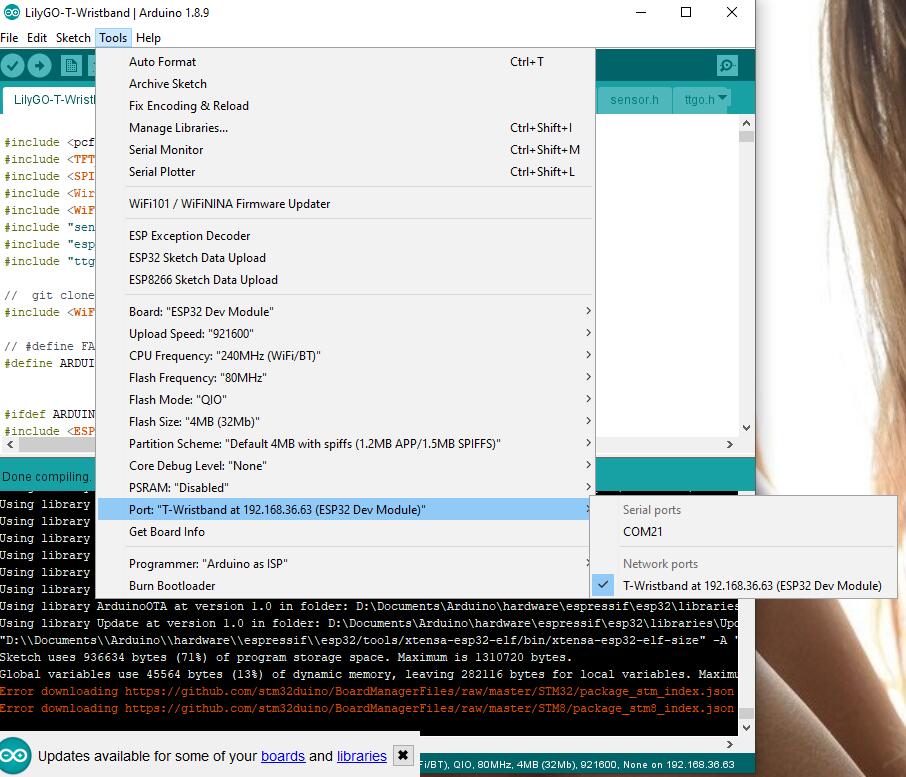
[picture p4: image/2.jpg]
        

6. `FACTORY_HW_TEST` 宏用于测试手环的硬件状态是否正常,默认关闭,如需开启请在`sketch`中开启
7. 触摸按钮当检测到按下则切换下一个功能
    - 按下第一次 将查看九轴传感器信息
    - 按下第二次 将进入深度睡眠
    - 在深度睡眠中,再次触碰 将唤醒手环

## 数据手册
- [MPU9250 Sensor](https://invensense.tdk.com/wp-content/uploads/2015/02/PS-MPU-9250A-01-v1.1.pdf)
- [ST7735](http://www.displayfuture.com/Display/datasheet/controller/ST7735.pdf)
- [ESP32-PICO-D4](https://www.espressif.com/sites/default/files/documentation/esp32-pico-d4_datasheet_en.pdf)
- [DRV2605](https://www.ti.com/product/DRV2605)
- 
## 引脚定义
| Name | Pin |
| --- | --- |
| TFT Driver | ST7735 |
| TFT_MISO | N/A |
| TFT_MOSI | 19 |
| TFT_SCLK | 18 |
| TFT_CS | 5 |
| TFT_DC | 23 |
| TFT_RST | 26 |
| TFT_BL | 27 |
| Touchpad | 33 |
| Touchpad Power | 25 |
| IMU Interrupt | 38 |
| RTC Interrupt | 34 |
| Battery ADC | 35 |
| VBUS ADC | 36 |
| I2C SDA | 21 |
| I2C SCL | 22 |
| LED and Vibration | 4 |
| CHARGE Indication | 38 |

- 振动模块 使用IO4进行驱动，与LED合并在一起

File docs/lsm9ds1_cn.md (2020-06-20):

## **[English](../examples/T-Wristband-LSM9DS1/README.MD) | 中文**

## 使用之前,请阅读下面的描述

1. 根据你使用的串口通讯板安装对应的驱动程序
   - [CP21xx Drivers](https://www.silabs.com/products/development-tools/software/usb-to-uart-bridge-vcp-drivers)
   - [CH340 Drivers](http://www.wch-ic.com/search?q=ch340&t=downloads)

2. 安装下面列表中的依赖库,默认已将所需要的库文件放置在`libdeps`目录中,请将`libdeps`目录内所有文件拷贝到`C:\<UserName>\Documents\Arduino\libraries`目录内
   - [TFT_eSPI](https://github.com/Bodmer/TFT_eSPI)
   - [PCF8563_Library](https://github.com/lewisxhe/PCF8563_Library)
   - [WiFiManager for esp32](https://github.com/tzapu/WiFiManager)
   - [SparkFun_LSM9DS1_Arduino_Library](https://github.com/sparkfun/SparkFun_LSM9DS1_Arduino_Library)

3. 配置TFT头文件(**如果使用`libdeps`目录中库文件,可以跳过这一步**)
    - 在你的库文件夹目录中找到**TFT_eSPI**目录
    - 在**TFT_eSPI**根目录中找到`User_Setup_Select.h`并且打开进行编辑
    - 将 文件头部`#include <User_Setup.h>` 注释掉
    - 找到 `#include <User_Setups/Setup26_TTGO_T_Wristband.h>`,取消前面的注释,保存退出
    - 最终效果如下图:
        
4. 板子可以选择**ESP32 Dev Module**，其他设置可以保持默认,注意 `T-Wristband` 没有使用PSRAM,请勿开启PSRAM,和调用PSRAM的功能函数

5. `ARDUINO_OTA_UPDATE` 宏用于**WiFiManager**和**OTA更新**,默认为关闭,如需开启请在`sketch`中开启
    - 当`ARDUINO_OTA_UPDATE`开启后,触摸按住按钮三秒钟进行`WiFi`重置
    - 开启OTA更新后,你可以在Arduino IDE端口中选择 `T-Wristband` 进行空中升级,如下图
        

6. `FACTORY_HW_TEST` 宏用于测试手环的硬件状态是否正常,默认关闭,如需开启请在`sketch`中开启
7. 触摸按钮当检测到按下则切换下一个功能
    - 按下第一次 将查看九轴传感器信息
    - 按下第二次 将进入深度睡眠
    - 在深度睡眠中,再次触碰 将唤醒手环

8. `ENABLE_BLE_DATA_TRANSMISSION` 宏用于测试BLE传输IMU数据示例 ,默认关闭, 可以使用`nRF Connect` , `LightBlue` 等APP 进行连接查看数据

9. `ENABLE_SENSOR`宏用于开启LSM9DS1传感器功能.默认关闭

10. `USE_PROTECTED_MEMBERS`宏用于开启LSM9DS1传感器关断模式功能.默认关闭,使用前请确保你已经将SparkFun_LSM9DS1_Arduino_Library 三个成员方法更改为共有成员方法，或者直接使用`libdeps`内的库文件

## 数据手册
- [lsm9ds1 Sensor](https://www.st.com/resource/en/datasheet/lsm9ds1.pdf)
- [ST7735](http://www.displayfuture.com/Display/datasheet/controller/ST7735.pdf)
- [ESP32-PICO-D4](https://www.espressif.com/sites/default/files/documentation/esp32-pico-d4_datasheet_en.pdf)

## 引脚定义
| Name | Pin |
| --- | --- |
| TFT Driver | ST7735 |
| TFT_MISO | N/A |
| TFT_MOSI | 19 |
| TFT_SCLK | 18 |
| TFT_CS | 5 |
| TFT_DC | 23 |
| TFT_RST | 26 |
| TFT_BL | 27 |
| Touchpad | 33 |
| Touchpad Power | 25 |
| RTC Interrupt | 34 |
| Battery ADC | 35 |
| I2C_SDA | 21 |
| I2C_SCL | 22 |
| CHARGE Indication | 32 |
| IMU INT1 | 38 |
| IMU INT2 | 39 |
| IMU INTM | 37 |
| IMU RDY | 36 |

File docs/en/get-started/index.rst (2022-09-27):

************
Get Started
************

This document is intended to guide users to build a software environment for T-Wristband hardware development.

Introduction
=============

T-Wristband supports the following features:

    * ESP32-PICO-D4
    * 9-axis Digital Motion Processor(PMU9250 or LSM9DS1)
    * PCF8563 Real-Time Clock
    * 0.96-inch IPS(80 * 160)
    * 120mAh Rechargeable Lithium Battery
    * TP4054 Battery Charging Chip
    * TTP223 Touch Button
    * MAX30102(optional)
    * DRV2605(optional)

What You Need
==============

Hardware:

* T-Wristband
* Programmer
* Computer running Windows, Linux, or macOS

Software:

* arduino
* platformio

.. todo: 开发板简介

Install prerequisites
======================

Please complete the installation of the tool first. The specific steps are as follows:

+-------------------+-------------------+
|     |  |
+-------------------+-------------------+
| `arduino`_        | `platformio`_     |
+-------------------+-------------------+





.. _arduino: https://docs.espressif.com/projects/arduino-esp32/en/latest/installing.html#installing-using-arduino-ide
.. _platformio: https://docs.espressif.com/projects/arduino-esp32/en/latest/installing.html#installing-using-platformio

Install serial driver
======================

Due to the shortage of chips and the price increase, T-Wristband's programmer has used cp21xx or ch340. You need to install the corresponding driver according to different Programmers.

* `CP21xx Drivers`_
* `CH340 Drivers`_

.. _CP21xx Drivers: https://www.silabs.com/products/development-tools/software/usb-to-uart-bridge-vcp-drivers
.. _CH340 Drivers: http://www.wch-ic.com/search?q=ch340&t=downloads

.. _Install dependent libraries:

Install dependent libraries
============================

T-Wristband requires the following dependency library support, users can use the library to manage the installation.

* `TFT_eSPI`_
* `PCF8563_Library`_
* `WiFiManager for esp32`_
* `SparkFun_LSM9DS1_Arduino_Library`_
* `Adafruit_DRV2605_Library`_
* `SparkFun_MAX3010x_Sensor_Library`_

.. _TFT_eSPI: https://github.com/Bodmer/TFT_eSPI
.. _PCF8563_Library: https://github.com/lewisxhe/PCF8563_Library
.. _WiFiManager for esp32: https://github.com/tzapu/WiFiManager
.. _SparkFun_LSM9DS1_Arduino_Library: https://github.com/sparkfun/SparkFun_LSM9DS1_Arduino_Library
.. _Adafruit_DRV2605_Library: https://github.com/adafruit/Adafruit_DRV2605_Library
.. _SparkFun_MAX3010x_Sensor_Library: https://github.com/sparkfun/SparkFun_MAX3010x_Sensor_Library

.. note::

    `libdeps <https://github.com/Xinyuan-LilyGO/LilyGo-T-Wristband/tree/master/libdeps>`_ saves the required dependencies, and `libdeps <https://github.com/Xinyuan-LilyGO/LilyGo-T-Wristband/tree/master/libdeps>`_ directory to ``C:\<UserName>\Documents\Arduino\libraries`` directory.

Configure TFT_eSPI
===================

.. note::

    If you use the library files in the `libdeps <https://github.com/Xinyuan-LilyGO/LilyGo-T-Wristband/tree/master/libdeps>`_ directory, you can skip this step

Modify the ``C:\<UserName>\Documents\Arduino\libraries\TFT_eSPI\User_Setup_Select.h`` file:

* Comment out the line ``#include <User_Setup.h>``
* Find the line ``#include <User_Setups/Setup26_TTGO_T_Wristband.h>`` and uncomment the previous

.. warning:: 

    If the screen has reversed colors, please refer to :ref:`Troubleshooting <tft_issue>`

Build example
==============

Open the corresponding example, select ``ESP32 Dev Module`` for the development board model, and keep other settings as default.

.. warning::

    T-Wristband does not use PSRAM, please do not enable PSRAM and call PSRAM related functions.

Programmer burning
===================

Using the Programmer, connect it to the T-Wristband via a cable.

OTA update
===========

T-Wristband does not have an onboard usb to ttl chip due to space problems, and it is inconvenient to open the shell to use the Programmer to burn. It is more convenient to choose OTA to upgrade.

#. Open ``ARDUINO_OTA_UPDATE`` in the source code, enable the OTA upgrade function, and use the Programmer to download the firmware.
#. ``WiFi`` reset by touching and holding the button for three seconds
#. Select ``T-Wristband`` in Arduino IDE port for over-the-air upgrade

Pinout
===========

==================== =========
Name                 Pin
==================== =========
TFT Driver           ST7735
TFT_MISO             N/A
TFT_MOSI             19
TFT_SCLK             18
TFT_CS               5
TFT_DC               23
TFT_RST              26
TFT_BL               27
Touchpad             33
Touchpad Power       25
RTC Interrupt        34
Battery ADC          35
I2C_SDA              21
I2C_SCL              22
CHARGE Indication    32
IMU INT1             38
IMU INT2             39
IMU INTM             37
IMU RDY              36
DRV_SDA              15
DRV_SCL              13
MAX3010X_SDA         15
MAX3010X_SCL         13
MAX3010X_IRQ         4
==================== =========

.. include:: datasheet.inc

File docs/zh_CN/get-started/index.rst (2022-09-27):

********
快速入门
********

本文档旨在指导用户搭建 T-Wristband 硬件开发的软件环境。

概述
====

T-Wristband 支持以下功能：

    * ESP32-PICO-D4
    * 9轴数字运动处理器（PMU9250 或者 LSM9DS1）
    * PCF8563 实时时钟芯片
    * 0.96英寸IPS（80 * 160）
    * 120mAh 可充电锂电池
    * TP4054 电池充电芯片
    * TTP223 触摸按键
    * MAX30102（可选）
    * DRV2605（可选）

准备工作
========

硬件：

* T-Wristband
* 烧录器
* 电脑（Windows、Linux 或 Mac OS）

软件：

* arduino
* platformio

.. todo: 开发板简介

安装准备
========

请先完成工具的安装，具体步骤见下：

+-------------------+-------------------+
|     |  |
+-------------------+-------------------+
| `arduino`_        | `platformio`_     |
+-------------------+-------------------+





.. _arduino: https://docs.espressif.com/projects/arduino-esp32/en/latest/installing.html#installing-using-arduino-ide
.. _platformio: https://docs.espressif.com/projects/arduino-esp32/en/latest/installing.html#installing-using-platformio

安装串口驱动
=============

因为芯片紧缺和涨价的原因，T-Wristband 的烧录器使用过 cp21xx 或者 ch340。需要根据不同的烧录器，安装对应的驱动程序。

* `CP21xx Drivers`_
* `CH340 Drivers`_

.. _CP21xx Drivers: https://www.silabs.com/products/development-tools/software/usb-to-uart-bridge-vcp-drivers
.. _CH340 Drivers: http://www.wch-ic.com/search?q=ch340&t=downloads

.. _安装依赖库:

安装依赖库
==========

T-Wristband 需要以下依赖库支持，用户可以用过库管理安装。

* `TFT_eSPI`_
* `PCF8563_Library`_
* `WiFiManager for esp32`_
* `SparkFun_LSM9DS1_Arduino_Library`_
* `Adafruit_DRV2605_Library`_
* `SparkFun_MAX3010x_Sensor_Library`_
* `MAX30208_Library`_

.. _TFT_eSPI: https://github.com/Bodmer/TFT_eSPI
.. _PCF8563_Library: https://github.com/lewisxhe/PCF8563_Library
.. _WiFiManager for esp32: https://github.com/tzapu/WiFiManager
.. _SparkFun_LSM9DS1_Arduino_Library: https://github.com/sparkfun/SparkFun_LSM9DS1_Arduino_Library
.. _Adafruit_DRV2605_Library: https://github.com/adafruit/Adafruit_DRV2605_Library
.. _SparkFun_MAX3010x_Sensor_Library: https://github.com/sparkfun/SparkFun_MAX3010x_Sensor_Library
.. _MAX30208_Library: https://github.com/Xinyuan-LilyGO/LilyGo-T-Wristband/tree/master/libdeps/MAX30208_Library

.. note::

    `libdeps <https://github.com/Xinyuan-LilyGO/LilyGo-T-Wristband/tree/master/libdeps>`_ 保存了所需要的依赖库，将 `libdeps <https://github.com/Xinyuan-LilyGO/LilyGo-T-Wristband/tree/master/libdeps>`_ 目录内所有文件拷贝到 ``C:\<UserName>\Documents\Arduino\libraries`` 目录即可。

配置 TFT_eSPI
==============

.. note::

    如果使用 `libdeps <https://github.com/Xinyuan-LilyGO/LilyGo-T-Wristband/tree/master/libdeps>`_ 目录中库文件,可以跳过这一步

修改 ``C:\<UserName>\Documents\Arduino\libraries\TFT_eSPI\User_Setup_Select.h`` 文件：

* 将 ``#include <User_Setup.h>`` 这一行注释掉
* 找到 ``#include <User_Setups/Setup26_TTGO_T_Wristband.h>`` 这一行，取消前面的注释

.. warning:: 

    如果屏幕出现反色的现象，请参考 :ref:`故障排查 <tft_issue>`

编译例程
========

打开对应的例程，开发板型号选择 ``ESP32 Dev Module``，其他设置可以保持默认。

.. warning::

    T-Wristband 没有使用PSRAM，请勿开启 PSRAM 和调用 PSRAM 相关的功能函数。

烧录器烧录
==========

使用烧录器，通过排线连接到 T-Wristband 。

OTA升级
========

T-Wristband 因为空间的问题，没有板载 usb to ttl 芯片，使用烧录器烧录需要打开外壳，有一定的不便。
选择 OTA 的方式升级，更加的方便。

#. 将示例代码中的 ``ARDUINO_OTA_UPDATE`` 打开，开启 OTA 升级功能，使用烧录器下载固件。
#. 触摸按住按钮三秒钟进行 ``WiFi`` 重置
#. 在Arduino IDE端口中选择 ``T-Wristband`` 进行空中升级

管脚布局
========

==================== =========
Name                 Pin
==================== =========
TFT Driver           ST7735
TFT_MISO             N/A
TFT_MOSI             19
TFT_SCLK             18
TFT_CS               5
TFT_DC               23
TFT_RST              26
TFT_BL               27
Touchpad             33
Touchpad Power       25
RTC Interrupt        34
Battery ADC          35
I2C_SDA              21
I2C_SCL              22
CHARGE Indication    32
IMU INT1             38
IMU INT2             39
IMU INTM             37
IMU RDY              36
DRV_SDA              15
DRV_SCL              13
MAX3010X_SDA         15
MAX3010X_SCL         13
MAX3010X_IRQ         4
==================== =========

.. include:: datasheet.inc

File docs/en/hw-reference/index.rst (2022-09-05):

*******************
Hardware Reference
*******************

.. toctree::
   :maxdepth: 1

    T-Wristband MPU9250 Version Schematic (PDF) <https://github.com/Xinyuan-LilyGO/LilyGo-T-Wristband/blob/master/schematic/T_Wristband_mpu9250.pdf>
    T-Wristband LSM9DS1 Version Schematic (PDF) <https://github.com/Xinyuan-LilyGO/LilyGo-T-Wristband/blob/master/schematic/T_Wristband_lsm9ds1_20200306.pdf>
    DRV2605 Vibration Module Schematic (PDF) <https://github.com/Xinyuan-LilyGO/LilyGo-T-Wristband/blob/master/schematic/T_Wristband_DRV2605.pdf>
    MAX30102 Heart Rate Module Schematic (PDF) <https://github.com/Xinyuan-LilyGO/LilyGo-T-Wristband/blob/master/schematic/T_Wristband_MAX30102.pdf>
    Shell Dimensions (DXF)  <https://github.com/Xinyuan-LilyGO/LilyGo-T-Wristband/blob/master/Shell_size.dxf>

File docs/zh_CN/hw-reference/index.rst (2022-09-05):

*********
硬件参考
*********

.. toctree::
   :maxdepth: 1

    T-Wristband MPU9250版本原理图 (PDF) <https://github.com/Xinyuan-LilyGO/LilyGo-T-Wristband/blob/master/schematic/T_Wristband_mpu9250.pdf>
    T-Wristband LSM9DS1版本原理图 (PDF) <https://github.com/Xinyuan-LilyGO/LilyGo-T-Wristband/blob/master/schematic/T_Wristband_lsm9ds1_20200306.pdf>
    DRV2605 拓展模块原理图 (PDF) <https://github.com/Xinyuan-LilyGO/LilyGo-T-Wristband/blob/master/schematic/T_Wristband_DRV2605.pdf>
    MAX30102 拓展模块原理图 (PDF) <https://github.com/Xinyuan-LilyGO/LilyGo-T-Wristband/blob/master/schematic/T_Wristband_MAX30102.pdf>
    外壳尺寸 (DXF)  <https://github.com/Xinyuan-LilyGO/LilyGo-T-Wristband/blob/master/Shell_size.dxf>

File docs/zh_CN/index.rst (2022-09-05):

.. zbhci documentation master file, created by
   sphinx-quickstart on Sat Dec 18 14:34:56 2021.
   You can adapt this file completely to your liking, but it should at least
   contain the root `toctree` directive.

T-Wristband 编程指南
====================

.. toctree::
    :maxdepth: 2

    快速开始 <get-started/index.rst>
    硬件参考 <hw-reference/index.rst>
    示例 <soft-reference/index.rst>
    故障排除 <troubleshooting>
    版权 <COPYRIGHT>

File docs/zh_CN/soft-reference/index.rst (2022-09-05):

*****
示例
*****

.. toctree::
    :maxdepth: 1

    LSM9DS1 <LSM9DS1>
    MPU9250 <MPU9250>
    DRV2605 <DRV2605>
    MAX3010X <MAX3010X>
    MAX30208 <MAX30208>

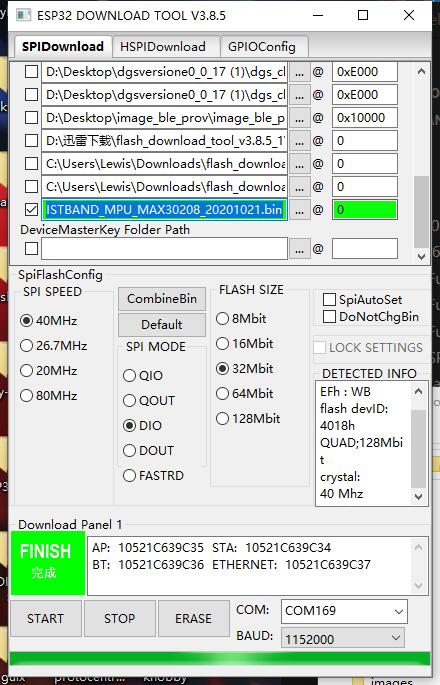
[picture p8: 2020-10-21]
firmware/T-Wristband-MAX30208-20201021/setting.jpg

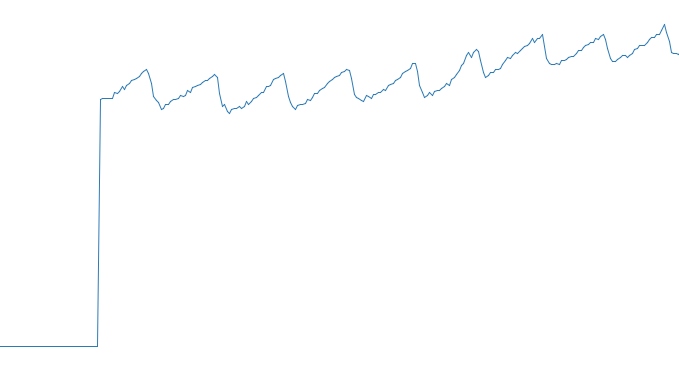
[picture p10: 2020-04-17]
libdeps/SparkFun_MAX3010x_Sensor_Library/extras/HeartBeat1.jpg

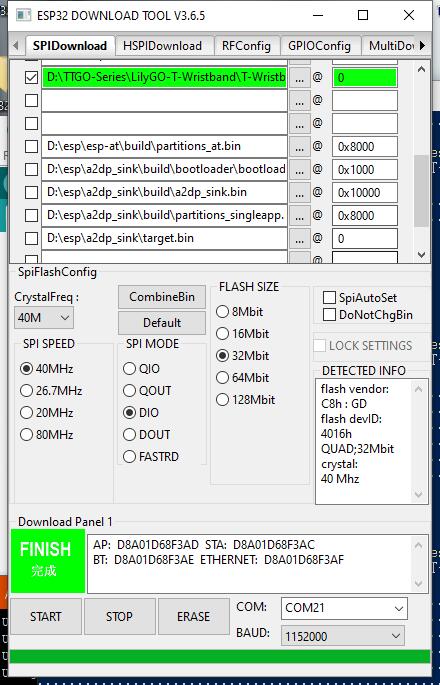
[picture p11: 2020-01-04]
firmware/T-Wristband-20200104/setting.jpg

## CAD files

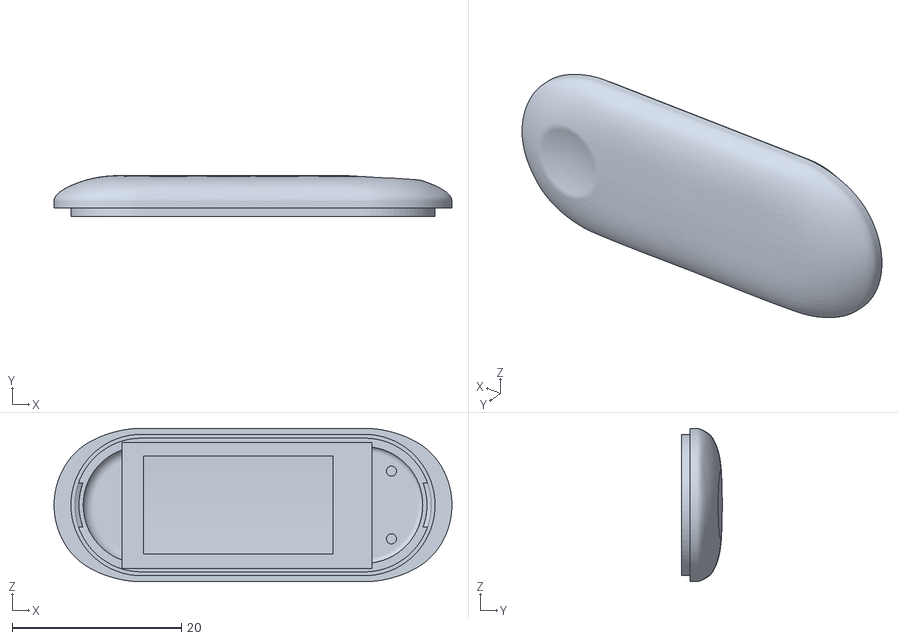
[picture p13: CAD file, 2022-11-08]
3D_files/prt0002.stl
47.0 x 4.80 x 18.1

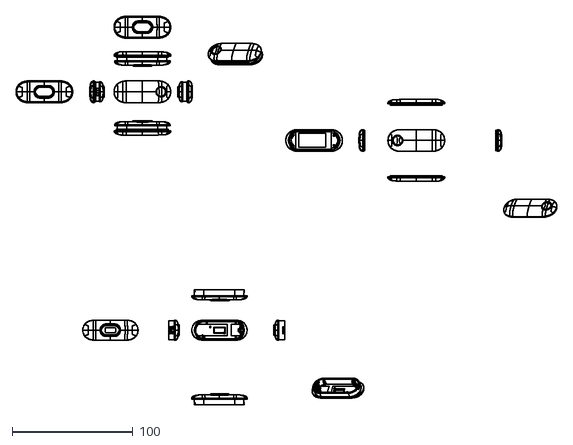
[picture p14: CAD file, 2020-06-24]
Shell_size.dxf
448.8 x 322.2

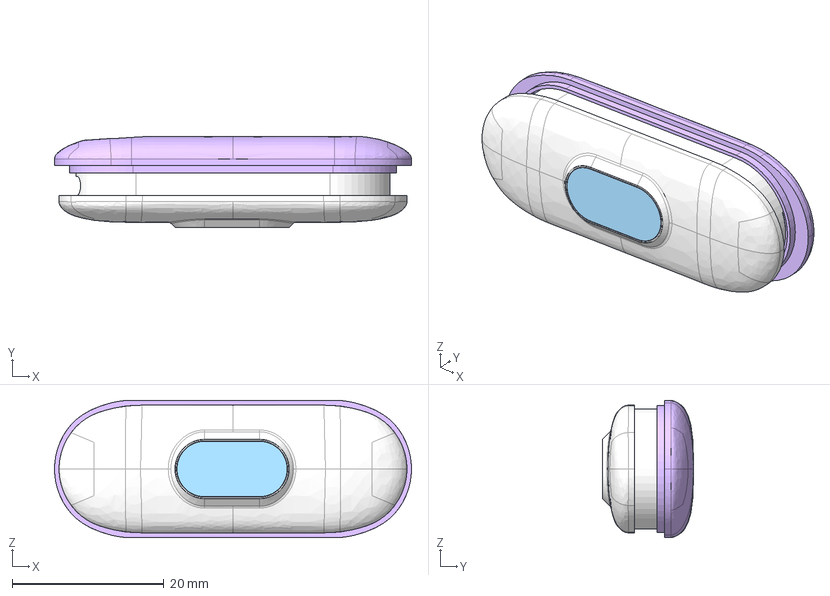
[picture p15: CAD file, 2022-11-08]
3D_files/3D_File.stp
47.0 x 12.0 x 18.1 mm
PRT0001
PRT0002
PRT0003 x 2
PRT0004

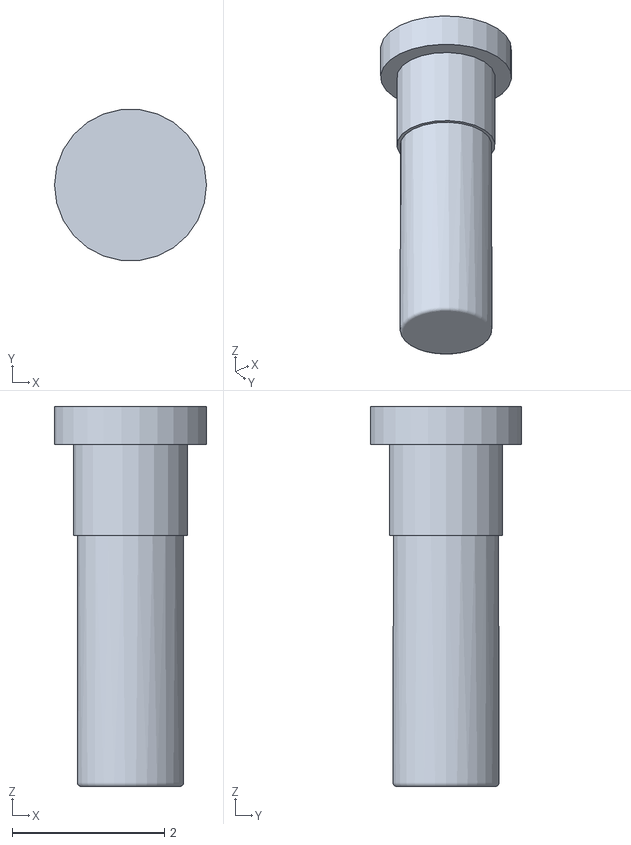
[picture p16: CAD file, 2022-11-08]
3D_files/prt0005.stl
2.00 x 1.99 x 5.00

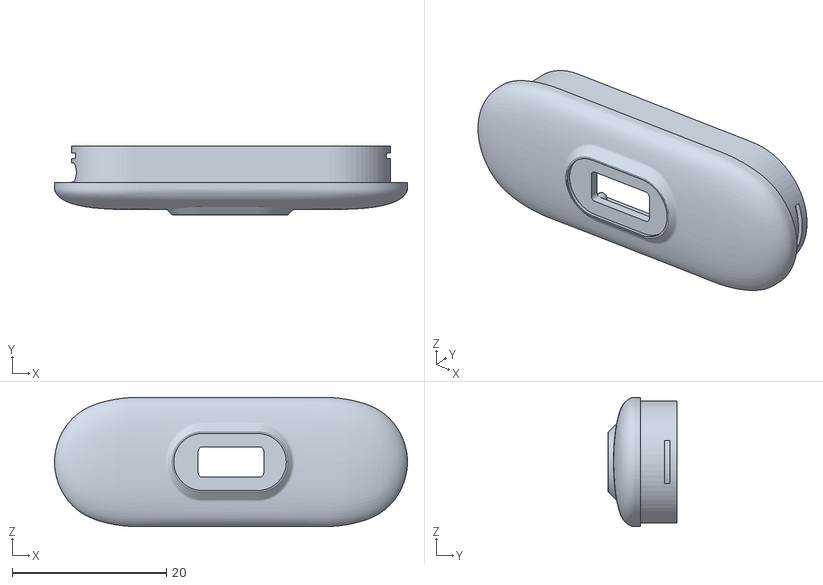
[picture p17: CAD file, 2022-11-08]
3D_files/prt0001.stl
45.8 x 8.90 x 16.8

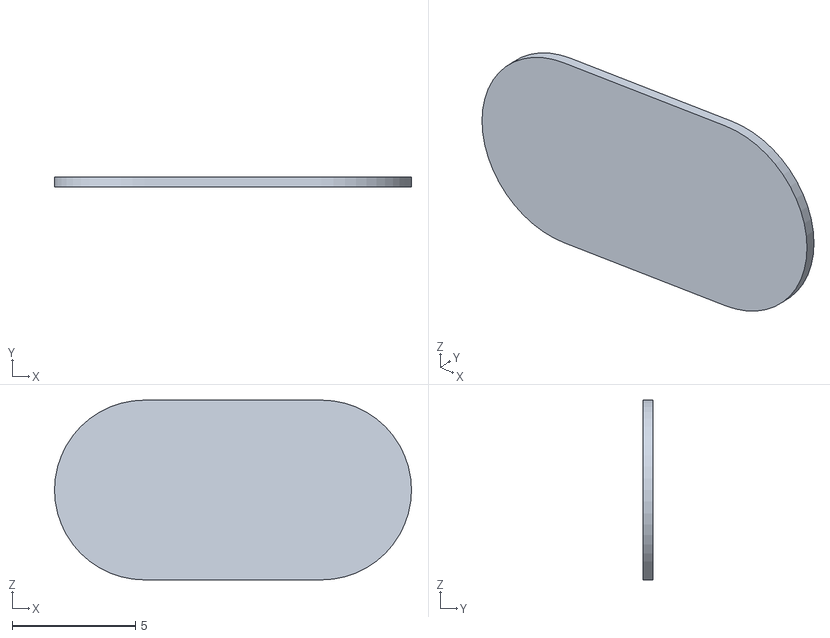
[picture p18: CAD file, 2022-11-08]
3D_files/prt0004.stl
14.5 x 0.4 x 7.30

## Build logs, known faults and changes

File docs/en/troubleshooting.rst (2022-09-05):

****************
Troubleshooting
****************

Hardware
=========

.. _tft_issue:

New version screens (with green labels) require configuration changes
----------------------------------------------------------------------

Due to supply problems, the new version of the screen and the old version of the screen configuration is different. The current (2022-09-05) shipments are all new version screens.



For different versions of the screen, you need to change the macro definition in ``C:\<UserName>\Documents\Arduino\libraries\TFT_eSPI\User_Setups\Setup26_TTGO_T_Wristband.h``:

* New version screen (with green label)



* old version screen



How to differentiate LSM9DS1 from MPU9250 sensor?
--------------------------------------------------

Please see the upper right half of the board below to distinguish:



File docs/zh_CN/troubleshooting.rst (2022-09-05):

********
故障排查
********

硬件
=====

.. _tft_issue:

新版本屏幕（有绿色标签）需要改变配置
-------------------------------------

因为供货的问题，新版本的屏幕与旧版本的屏幕的配置有所不同。目前（2022-09-05）出货均为新版本屏幕。



对于不同版本的屏幕，需要更改 ``C:\<UserName>\Documents\Arduino\libraries\TFT_eSPI\User_Setups\Setup26_TTGO_T_Wristband.h`` 中的宏定义：

* 新版本屏幕（有绿色标签）



* 旧版本屏幕



如何区分 LSM9DS1 与MPU9250 传感器？
-----------------------------------

请看下图板子的右上半部分，进行区分:



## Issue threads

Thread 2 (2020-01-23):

Sleep mode battery duration

TioRuben, 2020-01-23:
¿How much battery time do you get in sleep mode? I've tried with this code and mine [https://github.com/TioRuben/TTGO-T-Wristband-First-Steps](https://github.com/TioRuben/TTGO-T-Wristband-First-Steps) and barely get 1 day of battery in sleep mode.

PolyMeilex, 2020-01-25:
Same here, I have no idea how to improve it yet

TioRuben, 2020-01-25:
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

@PolyMeilex You are right, the battery management in my code it's still in progress and the code is reused from another project with Li-Ion battery, I should change to the values you propose, as the T-Wristband battery is Li-Po. But also need to port the ADC calibration code from LilyGo.

About the battery life, I've improved a little bit by adding some delays after LCD switch off and adding a reset before SLPIN:
```c++
  tft.writecommand(ST7735_SWRESET);
  delay(100);
  tft.writecommand(ST7735_SLPIN);
  delay(150);
  tft.writecommand(ST7735_DISPOFF);
```
(Point 9.12 of [Manufacturer's documentation](https://www.displayfuture.com/Display/datasheet/controller/ST7735.pdf)

And also disabling RTC timers, alarm and CLK:
```c++
  rtc.clearTimer();
  rtc.disableAlarm();
  rtc.disableCLK();
  rtc.disableTimer();
```
Now I get ~3 days of battery in sleep mode.

Will update my repo during the weekend.

PolyMeilex, 2020-01-25:
~3 days?? OMG! You are my saviour, thank you very much, I will test it in on my device right away

TioRuben, 2020-02-09:
Another thing to take in account is that, according to the schematic, the backlight LED seems not to have a current limiting resistor. In the case of my unit, it heats up a little bit near the union between the right side of the TFT and touch button. Maybe the current limiting resistor is embedded in the own display, but afterwards, I've configured PWM with about 72% duty cycle in TFT_BL pin without noticeable brightness change and a noticeable heat decrease.

Here is my TFT initialization code:
```c++
  tft.init();
  tft.setRotation(1);
  tft.setSwapBytes(true);
  tft.fillScreen(TFT_BLACK);
  ledcSetup(0, 5000, 8);
  ledcAttachPin(TFT_BL, 0);
  ledcWrite(0, 185);
```

The code can be improved to provide more duty cycle at day hours than in night hours.

primaldev, 2020-03-22:
Also putting the motion sensor to sleep will help a lot.

Just ad this to TioRuben's list:
`IMU.setSleepEnabled(true);`

hpsaturn, 2020-04-12:
@primaldev this is a good improvement, because not all of us, maybe need wake up the wristband after some  movements. Maybe it will be a setting from the user in the future for improve the battery life. I tested it on @TioRuben code and works fine.

PhilColbert, 2020-05-15:
I have the newer imu, have added all the ideas in this thread, but still getting 8-9 hours on sleep..... not much point of a watch that lasts 8 hours ?

Anyone got any further with this?

Thanks

boogie, 2020-05-16:
It's a pain for me as well, as I have bought a lot of t-wristbands. :/ Hope there's a solution for this.

PhilColbert, 2020-05-16:
Fortunately, I only got two to test, I hope theres a solution to this aswell as they look amazing.

The esp32 in deep sleep is supposed to pull between .15ma and 10µA so some other peripheral is still draining the battery.

The LSM9DS1 specs say 4.6ma during use and around 2.4 ma in sleep mode.
The pcf8563  is negligible.
The me6217 is 100uA.
So perhaps the screen is still drawing power ?

Ideas?

PhilColbert, 2020-05-18:
Just got a reply from lilygo saying the wristband should do 400UA in sleep... hopefully they will be able to get this, that would give around 8 days running which would be acceptable :)

PhilColbert, 2020-05-22:
No reply from lilygo, tried emailing them again.... not best service :(

boogie, 2020-05-28:
For a different hardware I have seen a tip, that you should set all the (SPI) ports of the display to LOW with digitalWrite, and that is the only way to reduce the power consumption. I have no tools now to check this theory for this band, but maybe you have.

PhilColbert, 2020-05-30:
Is that before sleep you mean ? I ran deep sleep at the start of setup() and managed to get 1.5ma current draw, still far away from the 400UA specified by lilygo.

I had a reply from lilygo , linking me to the documentation for esp deep sleep, completely pointless information again..

I have emailed back again asking how they get 400UA, I am feeling the lack of response isnt good

TheNitek, 2020-05-30:
Actually that may not be to bad of an advice because the ESP pins will float in deep sleep but there is an option to tell the ESP to keep certain pins in a specific state even while sleeping, so this might help to keep the display REALLY disabled while deep sleep.

TheNitek, 2020-05-30:
https://github.com/espressif/arduino-esp32/issues/2712

nav-andrea, 2020-06-08:
Hello, in our project we need to use BLE and WiFi
We've disabled all the process as you explain, also di display, and we use BLE 1 time every 30 seconds and WiFi 1 time every 15 minutes (using delay).
From 4.3V (max load) to 3.2V we've about 1 hour of usage. As the power reach 3.2V the device turn off. How can you have 3 days in sleep mode?
During sleep mode what kind of functionality could you have?

PhilColbert, 2020-06-09:
Unfortunately still no answer from lilygo after 3 emails about this problem :(

Renders the device useless for most cases I would think :(

boogie, 2020-06-09:
Indeed, it's a crap this way. I still hope it is fixable.

boogie, 2020-06-13:
**DONT BUY LILYGO® TTGO T-Wristband DIY Programmable Smart Bracelet**
It is useless, and they are still selling it.

I wrote to their technical email address (zhang@lilygo.cc) - no response, and to their business (lily@lilygo.cc) and sales (sales@lilygo.cc) about these issues. The "Quality guarantee" link is not working on their website (http://www.lilygo.cn/). I'm trying to get my money back.

boogie, 2020-06-15:
I got an answer. It is for development, I can upgrade the battery. I think it won't solve any of these problems.

hpsaturn, 2020-06-17:
@boogie but this is the reality, it is a development wristband, maybe can you work now in a possible software with this version, in mind in the future maybe **LilyGO** will launch a device with these issues fixed. For me its fine.

PhilColbert, 2020-06-17:
Thats pretty shocking, no where on their advertising say its for development.

No use for me if it only lasts a few hours!

boogie, 2020-06-18:
@hpsaturn I'm happy if it's good for you. Not for me. I've checked their Aliexpress site again, and this device is not advertised as a development wristband at all.

Also think it's not supportive that they're not responding in this thread, and I'm looking forward to see if they can share a code that proves the 400uA consumption they told us in email.

PhilColbert, 2020-06-18:
I have sent 6 emails so far with one response which was a link to the esp_deep_sleep code.... pointless.

Managed to get the sleep down to 1.5ma , if you just go into deep sleep on boot.... but still not good enough

Bearic, 2020-06-24:
I just wanted to chime in here. I received mine a few days ago, and after figuring out how to upload code, I just turned off the factory tests. I put it in deep sleep overnight ~10 hours and it's still at 3.88 V according to the display (~70%?). Maybe there were library updates that fixed it? Though I just noticed the time is off by about 30 minutes... Not sure why. Looking forward to playing with it some more.

hpsaturn, 2020-06-25:
Maybe @Bearic you could test [this firmware](https://github.com/TioRuben/TTGO-T-Wristband) too.
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
genotix, 2020-08-25:
I'll try to add this to the **SparkFunLSM9DS1.cpp** file to get the temperature

```
int16_t LSM9DS1::getTemp()
{
	readTemp();
	return temperature;
}
```
Don't expect it to be very precise.

boogie, 2020-08-25:
@genotix Wow! Is it working without modifying the hardware? Respect for figuring this out.

genotix, 2020-08-25:
> @genotix Wow! Is it working without modifying the hardware? Respect for figuring this out.

Well I surely do get a way better usage this way.
Still looking if this can be tweaked somewhat more.

genotix, 2020-08-25:
Sadly I just broke my screen of the LiliGo. :(
My next step would have been to make the update OTA by long pressing the wake button.

Opened a github page with my current developments:
https://github.com/genotix/LilyGO-T-Wristband

genotix, 2020-08-29:
Did some measurements:

00:10 => 89%
09:33 => 63%
19:30 => 48%
24:19 => 47%
34:19 => 25%
46:30 => Empty

So with this latest sketch it would function for about 40 hours I think.

As soon as I get the new watch I'll continue tuning.
(broke the screen of this one)
I also intend to dismantle the old watch to use it on a more sensitive Amp meter.

wide-area-devices, 2020-08-29:
Not sure why, maybe it's my multimeter but everything I try gets the circuit to be 1.77-2.09ma at best, this would mean a sleep time of 40ish hours at best

By taking the RTC and IMU off and putting on a different I2C tempsensor (controlled by gpio pin) I'm down to more like 0.2ma

I'm now looking towards the D4pico modules to see where I can get to with that and might if I'm unlucky have to prototype my own design that fits in the same case

Lilygo should have thought more in the design stage for sure

genotix, 2020-08-30:
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

Well that seems to be spot-on compared to my latest tests.

Being honest I am not sure what else we could do other than start desoldering components.

I agree with you on the fact that LiliGo could have done more to make the device more Low energy. Even with these on-board sensors. Surely a v2 could fix that and I would surely buy that.

biccius, 2021-02-08:
Going a little deeper into the initialization of the LSMD9DS1 I noticed that there is a call to the function init() that initialize the device with the default settings of Sparkfun that obviously do not take into account the sleep mode.

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

So I think that any settings made before are overwritten by this call

I suggest to comment it out

Personally I was able to go well over 24 hours of battery life (I'm using a 300mah) using appropriately deep sleep, cpuclock at 10mhz with jumps to 80mhz to make ble connections when necessary and accellerometer settings to low power

v44r, 2021-07-03:
I'm getting 0.43mA of current consumption on the t-wristband (MPU9250) with >4V on the battery right now... That's good enough for a few days on the 40mA battery (I have a vibration module so I cannot put the larger batteries on it).

The key is putting the MPU9250 to sleep (both accel/gyro AND magnetometer). Otherwise you get ~3.75mA.

This gets it down to 0.7mA:

	uint8_t b = _bus->readByte(MPU9250_ADDRESS, PWR_MGMT_1);
	_bus->writeByte(MPU9250_ADDRESS, PWR_MGMT_1, b | (1 << 6));

And this down to 0.43mA:

	_bus->writeByte(AK8963_ADDRESS, AK8963_CNTL, 0x00);

That's after normal usage (i.e., turn on wifi, accel/gyro/mag, tft, etc. and then turn them off and go to deep sleep leaving RTC alarm wakeup and button wakeup on):

	esp_sleep_enable_ext0_wakeup((gpio_num_t) RTC_INT_PIN, LOW); // wake by RTC
	esp_sleep_enable_ext1_wakeup(GPIO_SEL_33, ESP_EXT1_WAKEUP_ANY_HIGH); // wake by touch
	esp_deep_sleep_start();

ErickRBTK, 2021-08-03:
Les hace falta ver mas box.
se puede conseguir mas autonomia:
1 usando deepsleep cuando no se ocupa el ESP32
2 apaga la pantalla despues de 5 segundos
3 solo enciendes el wifi cuando lo usas
4 apaga el IMU si no lo usas
5 modificar el brillo pantalla segun la hora
6 bajar la velocidad del CPU

Tengo un MPU9250 con vibrador a 40mA. He conseguido unos 3 dias como reloj y boton wifi para mis proyectos. accel para cambiar horientacion, gyro off, mag off. en la foto ya lleva unas 12hrs desde que lo desconecte. trabajando en:
- brujula
- wom
- podometro
- alarma

https://1drv.ms/u/s!ArJwl0aLcuHssArITlP9b0-pt5qz

hpsaturn, 2021-08-06:
@ErickRBTK the thread is in English. But anyway, all here we already reached 3 days of duration, and I think that all here has implemented the same improvements.

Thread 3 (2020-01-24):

'ST7735_SLPIN' was not declared in this scope

wilksy, 2020-01-24:
Any help on this compile error?

wilksy, 2020-01-24:
Sorted Do not install library via Arduino IDE library manager. does not include up-to date defines.

Closed 2020-01-24.

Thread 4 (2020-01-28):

First time flash NON WIFI

kd4pba, 2020-01-28:
Please provide instructions for first time flash using programmer and NOT WIFI. Provided instructions for device seem to be a mix of confusing instructions.  It appears board needs to be installed in Arduino IDE first.  Also appears first time setup requires flash via USB NOT WIFI.  Very difficult to read into the instructions.

lewisxhe, 2020-02-13:
The factory is written with non-OTA firmware, so this is a problem, I should like to explain to them, or should I change the readme

lewisxhe, 2020-06-28:
If there are still problems, please reopen the issue

tejaswigowda, 2023-04-22:
MPU9250 code always enters OTA mode when enabled.

Closed 2020-06-28.

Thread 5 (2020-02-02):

Could not write

a9b, 2020-02-02:
I want help
Compilation succeeded, but could not write

This is Error message
```
Arduino：1.8.10 (Mac OS X), ボード："ESP32 Dev Module, Disabled, Default 4MB with spiffs (1.2MB APP/1.5MB SPIFFS), 240MHz (WiFi/BT), QIO, 80MHz, 4MB (32Mb), 115200, Verbose"
tool.py v2.6
Serial port /dev/cu.SLAB_USBtoUART
Connecting........_____....._____....._____....._____....._____....._____.....____スケッチの書き込み中にエラーが発生しました
_

A fatal error occurred: Failed to connect to ESP32: Timed out waiting for packet header
```

"ESP32 Dev Module" is selected in the procedure of the image below,
Port is "cu.SLAB_USBtoUAR"
https://github.com/Xinyuan-LilyGO/LilyGO-T-Wristband#3-precautions

lewisxhe, 2020-02-13:
Make sure your FPC terminals are not connected incorrectly

lewisxhe, 2020-06-28:
If there are still problems, please reopen the issue

Closed 2020-06-28.

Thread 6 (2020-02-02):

IMU_INT_PIN 38 or 39?

qgar12, 2020-02-02:
according to shematics IMU_INT_PIN =39
according to code & markdown IMU_INT_PIN =38

whats the right value?

Thx

TioRuben, 2020-02-02:
In the case of the unit I've is PIN 39

TioRuben, 2020-02-09:
FYI I've successfully set up wake on motion feature by sending this to MPU
```c++
  IMU.writeBit(MPU9250_ADDRESS, PWR_MGMT_1, 5, false);
  IMU.writeBit(MPU9250_ADDRESS, PWR_MGMT_1, 6, false);
  IMU.writeBit(MPU9250_ADDRESS, PWR_MGMT_1, 4, false);
  IMU.writeByte(MPU9250_ADDRESS, PWR_MGMT_2, 0x07);
  IMU.writeByte(MPU9250_ADDRESS, ACCEL_CONFIG2, 0x09);
  IMU.writeByte(MPU9250_ADDRESS, INT_ENABLE, 0x40);
  IMU.writeBit(MPU9250_ADDRESS, MOT_DETECT_CTRL, 7, true);
  IMU.writeBit(MPU9250_ADDRESS, MOT_DETECT_CTRL, 6, true);
  IMU.writeByte(MPU9250_ADDRESS, WOM_THR, 170);
  IMU.writeBit(MPU9250_ADDRESS, INT_PIN_CFG, 5, 0);
  IMU.writeByte(MPU9250_ADDRESS, INT_STATUS, 0);
  IMU.writeByte(MPU9250_ADDRESS, LP_ACCEL_ODR, 0x03);
  IMU.writeBit(MPU9250_ADDRESS, PWR_MGMT_1, 5, true);
```
[Invensense Datasheet](invensense.com/wp-content/uploads/2015/02/PS-MPU-9250A-01-v1.1.pdf) Pages 30 and 31 **"6.1 Wake-on-Motion Interrupt"**

And, setting up the EXT1 Wakeup
```c++
  pinMode(39, GPIO_MODE_INPUT);
  esp_sleep_enable_ext1_wakeup(GPIO_SEL_39, ESP_EXT1_WAKEUP_ANY_HIGH);
  esp_deep_sleep_disable_rom_logging();
  esp_deep_sleep_start();
```

Now I can move the arm towards my face to see the hour without touching any button.

lewisxhe, 2020-06-28:
If there are still problems, please reopen the issue

Closed 2020-06-28.

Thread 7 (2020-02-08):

GPIO on the main board

vvs551, 2020-02-08:
How to find any GPIO for the external connections on the main board?

lewisxhe, 2020-02-13:
This board does not have any external IO

lewisxhe, 2020-06-28:
If there are still problems, please reopen the issue

Closed 2020-06-28.

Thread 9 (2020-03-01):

OTA Hotspot not accessible

MauiKano, 2020-03-01:
I can flash the precompiled firmware T-Wristband-20200104 which brings me the WiFi manager
hotspot T-Wristband and I can configure WiFi. All works. Then I compile the latest Arduino source found in Xinyuan-LilyGo with the development branch of the WiFi manager. I can load the resulting firmware to my Wristband and it goes to the hotspot and shows the respective screen on the wristband but the WiFi is not announced. I can not find it when searching Wifi on my computer of phone. Any ideas ?

sysdl132, 2020-03-01:
Do you have a firewall?Or your library is no problem?You can try the master branch.
(Anyone can fix it or have a good idea?)

MauiKano, 2020-03-01:
I have a firewall but that is not the issue. the wristband hotspot works with the precompiled firmware.
I use the Wifi manager library by cloning that way:
git clone -b development https://github.com/tzapu/WiFiManager.git

sysdl132, 2020-03-01:
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
Do you tried master branch?

sysdl132, 2020-03-01:
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

MauiKano, 2020-03-01:
using the master branch I get a compile error:
Used: ...../sketchbook/hardware/espressif/esp32/libraries/WiFi
.........sketchbook/libraries/WiFiManager/WiFiManager.h:16:25: fatal error: ESP8266WiFi.h: No such file or directory

sysdl132, 2020-03-01:
Make sure you installed ESP8266 wifi library.
Maybe you can see README.md in WifiManager.
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

sysdl132, 2020-03-01:
You  can check them:
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
(I am not make sure)

MauiKano, 2020-03-01:
Doubt that these are needed.

How does the source code of the firmware T-Wristband-20200104  look like ? I am particularly interested how setupWiFi looks like. The current code is this: Is there a difference ?

void setupWiFi()
{
#ifdef ARDUINO_OTA_UPDATE
    WiFiManager wifiManager;

    //set callback that gets called when connecting to previous WiFi fails, and enters Access Point mode
    wifiManager.setAPCallback(configModeCallback);
    wifiManager.setBreakAfterConfig(true);          // Without this saveConfigCallback does not get fired
    wifiManager.autoConnect("T-Wristband");
#endif
}

is

MauiKano, 2020-03-04:
I found it :)
My hardware installation for ESP32 in the Arduino IDE was outdated. I installed fresh from here:
https://github.com/espressif/arduino-esp32
That solved the issue.

sysdl132, 2020-03-04:
Don't forget to update your outdated installation next time:D

MauiKano, 2020-03-05:
well. I had HW configured in arduono IDE via the json URL in preferences. That should give you auto update. However, there are various ESP32 HW branches out there. It would be good if you explicitly mention in the README the ESP32 git URL that is needed.

But i have a second issue now: A WiFi configuration is not stores persistently. If my wristband goes to sleep and rewoke again i have to configure wifi again:(

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

Closed 2020-03-04.

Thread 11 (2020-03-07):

Button is mechanically unstable

donatoaz, 2020-03-07:
Has anyone else experienced that the button never really works? I've tried it with several different debounce libraries and even my own code, and it never really works as expected, as if there was some really strange mechanical problem.

Has anyone tried to change the button for something else, or has any suggestion on how to troubleshoot it?

PolyMeilex, 2020-03-07:
For me it worked only when I pressed it really hard. I suspect it was same problem as yours, sadly I didn't find any solution for this. And it makes whole product literally unusable for me

donatoaz, 2020-03-07:
Yep, literally unusable for me as well, just lost half a saturday.

cpetito, 2020-03-12:
I also had an initial issue with the touch sensor.  I found that the sticky metal mesh on the underside of the cover needed to be moved a bit over so it made better contact with the spring contact on the PC board.

I suggest putting this code in your loop logic so you can see how the sensor is responding:

    if (digitalRead(TP_PIN_PIN) == HIGH) {
      digitalWrite(LED_PIN, HIGH);
    }
    else {
      digitalWrite(LED_PIN, LOW);
    }

With this code you can try touching the sensor pin with the cover off and see how that compares with touching the indent with the cover on.

I also noticed that when I put the cover on or put the module in the wrist strap, the sensor stays on for a few seconds.  This could be due to the TTP223-BA6's auto calibration, but I have not been able to find any information regarding the calibration algorithm.

jithurbide, 2020-04-27:
Hello,

I had a lot of issue with mine. Watch waking up without touching it. Button not working as expected. To solve it, I remove the conductive pad and move it from horizontal to vertical. I discovered that the connection from pad to pcb was not correct. May be it’s your problem. Try to repositioning the conductive pad.

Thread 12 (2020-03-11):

'MPU9250' does not name a type

bvandenberg, 2020-03-11:
When uploading the example program I get the following error. How to resolve? Thank you!
`'MPU9250' does not name a type`

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

cpetito, 2020-03-12:
You need to have these other files in the sketch folder:

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

lewisxhe, 2020-06-18:
As @cpetito said, you did not check the README carefully

UPocek, 2023-01-23:
Try prefixing class declaration with bfs::

```
bfs::Mpu6500 mpu6500(&SPI, 2);
```

this works for me

Closed 2020-06-18.

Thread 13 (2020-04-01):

ST7735_x not delared in this scope

Korvian, 2020-04-01:
I'm using Arduino IDE and when compiling I get the following errors:
'ST7735_SLPIN' was not declared in this scope
'ST7735_DISPOFF' was not declared in this scope

The related lines are 503 and 504 from LilyGO-T-Wristband.ino
tft.writecommand(ST7735_SLPIN);
tft.writecommand(ST7735_DISPOFF);

I've followed the Readme.md as best I can but it is not clear for me.

codebombi, 2022-01-24:
Did you manage to fix it?

Closed 2020-04-02.

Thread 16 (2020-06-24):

Tap detection in the MPU9250 library please?

mdaughtrey, 2020-06-24:

mdaughtrey, 2020-06-24:
As above

lewisxhe, 2020-06-28:
It seems that there is no, this is just a driver file, behavior detection is not here, and SparkFun_MPU-9250-DMP_Arduino_Library will be used later

mdaughtrey, 2020-06-28:
Ok thanks.
Does the Sparkfun library need to be ported to use the I2C interface? If so
I'm going to try to do it.

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

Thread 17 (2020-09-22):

display in sleep mode

biccius, 2020-09-22:
I would like to try to restore the screen display after a deep sleep as quickly as possible without do a full re-initialization of the display.

Following commands works if called sequentially in setup() for example
```

		digitalWrite(TFT_BL, LOW);
		tft.writecommand(ST7735_SLPIN);

	        digitalWrite(TFT_BL, HIGH);
		tft.writecommand(ST7735_SLPOUT);
```

But after a deep sleep of ESP32 the "SLEEP OUT" commands of display seems never work.
I think becase the display is reset from ESP32's reset pin (IO26?) asserted LOW when the mcu is in deep sleep. So a re-initialization via SPI seems to be necessary.

Is there any way to keep the buffer display preserved after a ESP32 deep sleep without change the hardware?

Thanks

Closed 2020-09-25.

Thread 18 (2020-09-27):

Flashing for the first time using the Flash tool board & T-Wristband

smtre, 2020-09-27:
Hi All,

I am having trouble flashing the T-Writsband.  I have purchased three bands and and attempted the following on all of them.

I don't believe that it is a hardware issue, as I have three of them and tried them all.

It seems that no matter what I do I cannot get this to flash.  Clearly there is something I do not understand.

Any help greatly appreciated.

Cheers,

Scott

Environment
============

I have followed these instructions: https://github.com/Xinyuan-LilyGO/LilyGo-T-Wristband/blob/master/examples/T-Wristband-LSM9DS1/README.MD

I have also read this FAQ - especially paragraph 5.1.v: https://github.com/Xinyuan-LilyGO/LilyGo-Document

I have both the recommended USB drivers installed (first recommended by the instructions above, the second from the FAQ)
http://www.wch-ic.com/search?q=ch340&t=downloads
https://www.silabs.com/products/development-tools/software/usb-to-uart-bridge-vcp-drivers

I am using the example code with no changes from the Xinyuan-LilyGO / LilyGo-T-Wristband repo: T-Wristband-LSM9DS1.ino

I have the code compiling in the Arduino IDE by following the instructions above.

I have the Arduino IDE Board manager configured the same as point 5 in the instructions:  https://github.com/Xinyuan-LilyGO/LilyGo-T-Wristband/blob/master/examples/T-Wristband-LSM9DS1/README.MD
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

The Flash tool board I have is CH340C v2.0 20200324

I have the LSM9DS1 T-Wristband version of the board, confirmed with the photo here: https://github.com/Xinyuan-LilyGO/LilyGo-T-Wristband

I have the flash tool board laying flat on the desk and the micro ribbon with the white line facing up plugged into the T-Wristband board.
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

Error
============

I go to upload the board and get the following errors

"C:\\Users\\Scott\\AppData\\Local\\Arduino15\\packages\\esp32\\tools\\xtensa-esp32-elf-gcc\\1.22.0-80-g6c4433a-5.2.0/bin/xtensa-esp32-elf-size" -A "C:\\Users\\Scott\\AppData\\Local\\Temp\\arduino_build_124587/T-Wristband-LSM9DS1.ino.elf"
Sketch uses 940818 bytes (71%) of program storage space. Maximum is 1310720 bytes.
Global variables use 45784 bytes (13%) of dynamic memory, leaving 281896 bytes for local variables. Maximum is 327680 bytes.
C:\Users\Scott\AppData\Local\Arduino15\packages\esp32\tools\esptool_py\2.6.1/esptool.exe --chip esp32 --port COM5 --baud 921600 --before default_reset --after hard_reset write_flash -z --flash_mode dio --flash_freq 80m --flash_size detect 0xe000 C:\Users\Scott\AppData\Local\Arduino15\packages\esp32\hardware\esp32\1.0.4/tools/partitions/boot_app0.bin 0x1000 C:\Users\Scott\AppData\Local\Arduino15\packages\esp32\hardware\esp32\1.0.4/tools/sdk/bin/bootloader_dio_80m.bin 0x10000 C:\Users\Scott\AppData\Local\Temp\arduino_build_124587/T-Wristband-LSM9DS1.ino.bin 0x8000 C:\Users\Scott\AppData\Local\Temp\arduino_build_124587/T-Wristband-LSM9DS1.ino.partitions.bin
esptool.py v2.6
Serial port COM5
Connecting........_____....._____....._____....._____....._____....._____....._____

A fatal error occurred: Failed to connect to ESP32: Timed out waiting for packet header
A fatal error occurred: Failed to connect to ESP32: Timed out waiting for packet header

Attempted Fixes
============

I have attempted:

1. pressing and holding the IO1 button for the entire Connecting........ stage
2. pressing and holding the IO1 & RST buttons for the entire Connecting........ stage
3. pressing and holding the IO1 then pressing the RST button and releasing both buttons during the Connecting........ stage
4. pressing and holding the RST then pressing the IO1 button and releasing both buttons during the Connecting........ stage
5. I have repeated the above procedure on a second and third flash tool board and second and third T-Wristband board
6. I have repeated the above procedure on a mixing the first and second and third boards in combination
7. I have updated Arduino IDE to 1.8.13 and repeated attempts 1-4
8. I have updated all of the libraries in my environment - including ones not used by the code - and repeated attempts 1-4

smtre, 2020-09-27:
The Verbose Compile messages from the IDE are here
[verbose.txt](https://github.com/Xinyuan-LilyGO/LilyGo-T-Wristband/files/5287543/verbose.txt)

smtre, 2020-09-28:
Solved it.

For those of you who don't know the little connector on the board has a clip!  Who knew!

You need to lift the clip up with your finger nail then place in the cable then CLIP is down properly.

Magically it all starts uploading.

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

Closed 2020-09-28.

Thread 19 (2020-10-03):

tft reinit after deep sleep

biccius, 2020-10-03:
Hi

This is meant to be an attempt to try and improve the display drawing speed after the ESP32 wakes up from deep sleep. In all the sources I've seen, the display call tft.init() at every wake of the microcontroller.
This include a hardware or software reset that blank the screen for some milliseconds.

The ST7735 display has sleep and shutdown commands, preserving the contents of the on-screen buffer in memory.

My purpose is to try to:

    fill the screen with a color A
    send the esp32 to deep sleep
    wake up with button press the esp32 and redraw the display with color A
    then change in progression colors to B, C , etc..

Here's the code i'm working on:

```
#include <pcf8563.h>
#include <TFT_eSPI.h>            // Graphics and font library for ST7735 driver chip
#include <SPI.h>
#include <WiFi.h>
#include <Wire.h>
#include "sensor.h"
#include "esp_adc_cal.h"

#define TP_PIN_PIN          33
#define TP_PWR_PIN 			25

TFT_eSPI tft = TFT_eSPI();       // Invoke library, pins defined in User_Setup.h
RTC_DATA_ATTR int boots = 0;

void setupTFT()
{
  tft.init();
  tft.setRotation(1);
  tft.setSwapBytes(true);
}

int color = 0x5555;

void Wake()
{
    SPI.begin(TFT_SCLK, TFT_MISO, TFT_MOSI, -1);
    pinMode(TFT_CS, OUTPUT);
    pinMode(TFT_DC, OUTPUT);
    pinMode(TFT_BL, OUTPUT);
	tft.writecommand(ST7735_DISPON);
	tft.writecommand(ST7735_SLPOUT);
}

void Sleep()
{
  tft.writecommand(ST7735_SLPIN);
  tft.writecommand(ST7735_DISPOFF);
  delay(200);

  digitalWrite(GPIO_NUM_26, HIGH);  // keep GPIO_26 high state after deep sleep reset
  gpio_hold_en(GPIO_NUM_26);		// display is preserved
  gpio_deep_sleep_hold_en();

  esp_sleep_enable_ext1_wakeup(GPIO_SEL_33, ESP_EXT1_WAKEUP_ANY_HIGH);
  esp_deep_sleep_start();
}

void setup(void)
{
	  pinMode(TP_PIN_PIN, INPUT);
	  pinMode(TP_PWR_PIN, PULLUP);
	   //! Must be set to pull-up output mode in order to wake up in deep sleep mode
	   digitalWrite(TP_PWR_PIN, HIGH);

	  Serial.begin(115200);

	  if(boots == 0) //Run this only the first time
	  {
		  Serial.println("first boot");
		  setupTFT();
		  tft.fillScreen(color);
		  color+=0x1000;
	  	  boots ++;
	  }
	  else
	  {
		  Serial.println("wake");
		  Wake();
		  tft.setRotation(1);
		  tft.setSwapBytes(1);
		  while (1)
		  {
			  Serial.println("changing color");
			  tft.fillScreen(color);
			  color+=0x1000;
			  delay(1000);
		  }
	  }//if boots
}

void loop()
{
	delay(5000);
	Serial.println("sleep");
	Sleep();
}
```

Can't understand why after the wake up the display is not working as expected

genotix, 2020-10-04:
Not fully into this but looking at your code some questions pop-up which might help you:
1. Isn't there an SPI.end() or SPI.stop() or something that you should induce on sleep?
2. I would first power the display, pause and then initialise SPI.
3. What happens to your PULLUP value on the TP_PWR_PIN after a reboot and the pwer state of this pin (HIGH?)
4. If you maintain the display to show it's last state in deep-sleep mode perhaps it loses sync with SPI or something so perhaps a short power off followed by short delay and power on is required?

Would like to know your outcome.

Regards,

Eric

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

biccius, 2020-10-04:
Hi Eric

1. SPI.end() detach all SPI pins (MISO,MOSI,CLOCK,CS) previously attached by SPI.begin() to signals events. I think is useless add it before the sleep because at restart the peripheral is uninitialized because the chip is reset by the deep sleep.
2. According to schematics of the display (
https://github.com/Xinyuan-LilyGO/LilyGo-T-Wristband/blob/master/schematic/T_Wristband_lsm9ds1_20200306.pdf) we can just send a RESET signal on RES pin. I want to avoid this because the display is already initialized.

In the sleep phase we use
 ```
 tft.writecommand(ST7735_SLPIN);
  delay(150);
  tft.writecommand(ST7735_DISPOFF);
  delay(200);
```
In wake up we have to do the same with SLPOUT and DISPON but before do that we have to re-initialize the SPI perpipheral
3. This pin is used by touchpad to wakeup the device. Actually I find this pointless because the sleep is working correctly for me.
4. If we do a tft.init() everything restart to work correctly. This method called at every wake is very slow so re-init the display with all SPI commands is what i'm trying to do. I already do DISPON  and DISPOFF commands on the display and the display turn on correctly after the sleep for me.

Here's my last source revision

```
#include <pcf8563.h>
#include <TFT_eSPI.h>            // Graphics and font library for ST7735 driver chip
#include <SPI.h>
#include <WiFi.h>
#include <Wire.h>
#include "sensor.h"
#include "esp_adc_cal.h"

#define TP_PIN_PIN          33
#define TP_PWR_PIN 			25

TFT_eSPI tft = TFT_eSPI();       // Invoke library, pins defined in User_Setup.h
RTC_DATA_ATTR int boots = 0;

void setupTFT()
{
  tft.init();
  tft.setRotation(1);
  tft.setSwapBytes(true);
}

int color = 0x5555;

void Wake()
{

    pinMode(TFT_CS, OUTPUT);
    pinMode(TFT_DC, OUTPUT);
    pinMode(TFT_BL, OUTPUT);

    digitalWrite( TFT_BL , HIGH);

    SPI.begin(TFT_SCLK, TFT_MISO, TFT_MOSI, -1);

    tft.writecommand(ST7735_DISPON);
    delay(150);
	tft.writecommand(ST7735_SLPOUT);
	delay(150);
}

void Sleep()
{
  tft.writecommand(ST7735_SLPIN);
  delay(150);
  tft.writecommand(ST7735_DISPOFF);
  delay(200);

  digitalWrite(GPIO_NUM_26, HIGH);  // keep GPIO_26 high state after deep sleep reset
  gpio_hold_en(GPIO_NUM_26);		// display is preserved
  gpio_deep_sleep_hold_en();

  digitalWrite( TFT_BL , LOW);

  SPI.end();

  esp_sleep_enable_ext1_wakeup(GPIO_SEL_33, ESP_EXT1_WAKEUP_ANY_HIGH);
  esp_deep_sleep_start();
}

void setup(void)
{
	  pinMode(TP_PIN_PIN, INPUT);
	  pinMode(TP_PWR_PIN, PULLUP);
	  //! Must be set to pull-up output mode in order to wake up in deep sleep mode
	  digitalWrite(TP_PWR_PIN, HIGH);

	  Serial.begin(115200);

	  if(boots == 0) //Run this only the first time
	  {
		  Serial.println("first boot");
		  setupTFT();
		  tft.fillScreen(color);
		  color+=0x1000;
	  	  boots ++;
	  }
	  else
	  {
		  Serial.println("wake");
		  Wake();
		  tft.setRotation(1);
		  tft.setSwapBytes(1);
		  delay(3000);
		  while (1)
		  {
			  Serial.println("changing color");
			  tft.fillScreen(color);
			  color+=10;
			  delay(10);
		  }
	  }//if boots
}

void loop()
{
	delay(5000);
	Serial.println("sleep");
	Sleep();
}
```

What the code do is :
1. display start with cyan screen
2. deepsleep after 5 seconds
3. wakeup at button press with immediate display cyan screen shown
4. after the wakeup the display start cycling redrawing the display with differents colors

Everything works, but at point 4 i have the display like in figure

[IMAGE](https://i.ibb.co/nMWTMLX/Whats-App-Image-2020-10-04-at-18-39-30.jpg)

So i think the tft library restart in a wrong state or the display need to be re-initialized in some way

genotix, 2020-10-04:
Hi!

See inline my response

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
I know that normally a return from a deep sleep is a full reset.
You don't notify the display of this though.
I'm not sure what happens to the bus connection of the display once you stop the clock.
The clock of the SPI interface will likely stop on deep sleep.
It is likely that the display will need some kind of "kick" to make sure it accepts data again.

Since you explicitly -disconnect- from the display without really letting it know that SPI might become reset and the clock being stopped this might cause the SPI bus of the display to crash and show a noisy framebuffer image. (which looks fairly like the image you get)

> According to schematics of the display (
> https://github.com/Xinyuan-LilyGO/LilyGo-T-Wristband/blob/master/schematic/T_Wristband_lsm9ds1_20200306.pdf <https://github.com/Xinyuan-LilyGO/LilyGo-T-Wristband/blob/master/schematic/T_Wristband_lsm9ds1_20200306.pdf>) we can just send a RESET signal on RES pin. I want to avoid this because the display is already initialized.
Hmm check out this document; it's the display datasheet:
https://datasheetspdf.com/pdf-file/694957/SitronixTechnology/ST7735/1 <https://datasheetspdf.com/pdf-file/694957/SitronixTechnology/ST7735/1>

From the display sheet i see it can also have a Parallel interface active.
Perhaps that one kicks in after the reset causing the issues.

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
Hmm have you by any chance tried to change the order of the write commands to turn the display on again perhaps to see if this has a positive effect?
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
Where did you get this from?
I would not do that unless you're absolutely correct on this one.
Since the pull-up is something like a 4k7 resistor it might wake up the chip of the TFT yet not sufficient enough perhaps corrupting the existing memory.
Are you positive on this one?

I hope you get it fixed!
Good luck!
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

biccius, 2020-10-06:
I think you may be right about asynchronously blocking communication between ESP32 and the display.
Just adding SPI.end doesn't seem to give improvements

Not even changing the order of the write commands seems to change anything either

It could be that restarting the ESP32 at reset sends something strange to the already configured display and causes that horizontal bar not to be redrawn.

I can't understand what you're referring to in the last part of the post.

genotix, 2020-10-13:
Give my code a try:
https://github.com/genotix/LilyGO-T-Wristband

Verstuurd vanaf mijn iPad

> Op 3 okt. 2020 om 19:08 heeft Fabrizio Benatti <notifications@github.com> het volgende geschreven:
>
> SPI.begin(

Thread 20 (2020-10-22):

LILYGO T-Wristband Motor vibration code and bluettoth

inoffice, 2020-10-22:
Hi and good day
I looking for a code to Bluettooth BLE server to activate vibration motor, because not see vibration motor pin (MPU sensor?).
BEST REGARDS

inoffice, 2020-10-26:
> Hi and good day
> I looking for a code to Bluettooth BLE server to activate vibration motor, because not see vibration motor pin (MPU sensor?).
> BEST REGARDS

inoffice, 2020-10-26:
Hi and good day
I looking for a code to Bluettooth BLE server to activate vibration motor, because not see vibration motor pin (MPU sensor?).
BEST REGARDS

Closed 2020-10-26.

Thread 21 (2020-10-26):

Bluetooth BLE and vibration motor activate?

inoffice, 2020-10-26:
Hi and good day
I looking for a code to Bluettooth BLE server to activate vibration motor, because not see vibration motor pin (MPU sensor?).
BEST REGARDS

inoffice, 2020-10-28:
I respond self, the motor vibration ative with PIN_LED .

BEST REGARDS

genotix, 2020-10-28:
Lol, that sounds contra-intuitive

Met vriendelijke groet / Kind regards,

Eric Oud Ammerveld
Phone:
+31 10 495 19 55
Mobile:
+31 6 55 86 25 44
E-mail:
eric@genotix.nl

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

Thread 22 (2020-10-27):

Impossible programming?

inoffice, 2020-10-27:
Hi and good day

Serial port COM7
Connecting........_____....._____....._____....._____....._____....._____.....____Ha ocurrido un error mientras se enviaba el sketch

I try hold button of program PCB and same!
How i can programming?
BEST REGARDS

genotix, 2020-10-27:
1. Lower your baud rate and try again.
2. If it doesn’t work, goto 1

Met vriendelijke groet / Kind regards,

Eric Oud Ammerveld
Phone:
+31 10 495 19 55
Mobile:
+31 6 55 86 25 44
E-mail:
eric@genotix.nl

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

inoffice, 2020-10-28:
Hi and good day
Great Resolve!! thanks

genotix, 2020-10-28:
Good luck!

Met vriendelijke groet / Kind regards,

Eric Oud Ammerveld
Phone:
+31 10 495 19 55
Mobile:
+31 6 55 86 25 44
E-mail:
eric@genotix.nl

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

Closed 2022-09-05.

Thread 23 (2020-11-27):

2 Minor bugs in RTC_Show

mikeprice99, 2020-11-27:
(Using T-Wristband-LSM9DS1.ino for line numbers ...)
In RTC_Show function:

1/
line 690 = <code>tft.setTextColor(0xFBE0, TFT_BLACK); // Orange</code>
but by setting background color the 'ghost' image is overwritten. So the line should be
 <code>tft.setTextColor(0xFBE0); // Orange </code>

2/
line 704, setting the color for drawing the colon is in the wrong block, causing the colon to be displayed in the wrong color if the voltage has changed within the current minute.
currently =
`if (ss % 2) { // Flash the colon`
            `tft.setTextColor(0x39C4, TFT_BLACK);`
            `xpos += tft.drawChar(':', xcolon, ypos, 7);`
            `tft.setTextColor(0xFBE0, TFT_BLACK);`
        `} else {`
            `tft.drawChar(':', xcolon, ypos, 7);`
        `}`

should be
`if (ss % 2) { // Flash the colon`
`            tft.setTextColor(0x39C4, TFT_BLACK);`
`            xpos += tft.drawChar(':', xcolon, ypos, 7);`
`        } else {`
`            tft.setTextColor(0xFBE0, TFT_BLACK);`
`            tft.drawChar(':', xcolon, ypos, 7);`
`       }`

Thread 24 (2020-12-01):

How NRF52832 Module is programming?

furkanisikay, 2020-12-01:
Hello,

I bought a nrf52832 model ttgo t wristband. I did not program with mpu9250 example or lms91d example. it did not work.

Arduino ide give says ;
Sketch uses 719322 bytes (54%) of program storage space. Maximum is 1310720 bytes.
Global variables use 40352 bytes (12%) of dynamic memory, leaving 287328 bytes for local variables. Maximum is 327680 bytes.
esptool.py v2.6
Serial port COM4
Connecting........_____....._____....._____....._____....._____....._____.....____An error occurred while uploading the sketch
_

A fatal error occurred: Failed to connect to ESP32: Timed out waiting for packet header

Also, I tried lower bandwith but it did not work.

How I program this module? Which library can I use for programming this module?

genotix, 2020-12-01:
Lower your communication speed to 115200

Met vriendelijke groet / Kind regards,

Eric Oud Ammerveld
Phone:
+31 10 495 19 55
Mobile:
+31 6 55 86 25 44
E-mail:
eric@genotix.nl

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

furkanisikay, 2020-12-03:
It did not work.

genotix, 2020-12-03:
Then you might have either a faulty programmer, connection or chip

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

furkanisikay, 2020-12-04:
I tried with 8 another programmer.I tried with 3 another cables and ports. In addition, I programmed another mpu 9250 models with programmer that I used before. Finally, my idea is "we have to use another sdk for this models" or "I have product that is crashed".

genotix, 2020-12-04:
Hmm sounds like it is crashed?

Met vriendelijke groet / Kind regards,

Eric Oud Ammerveld
Phone:
+31 10 495 19 55
Mobile:
+31 6 55 86 25 44
E-mail:
eric@genotix.nl

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

fgmn, 2022-03-11:
I have the same problem, have you solved it?

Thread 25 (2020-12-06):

Yaw value problem

fabioetec, 2020-12-06:
I would like to develop a compass.

So I modified MPU9250 example creating a sprite with an arrow which I rotate with the angle returned by IMU.yaw.

If I correctly understand IMU.yaw should give me the angle in degrees from north to the current orientation.

The problem is IMU.yaw return me completly random values, for example without moving the device and setting `#define SerialDebugMPU9250 true` on sensor.h I get:

```
ax = 42.85 ay = -302.12 az = -1009.95 mg
gx = -0.11 gy = 0.30 gz = 0.05 deg/s
mx = -69 my = -468 mz = -464 mG
-0.10-0.100.83-0.54
Yaw, Pitch, Roll:
-185.50, -15.81, -114.78
ax = 42.79 ay = -307.19 az = -1008.85 mg
gx = -0.21 gy = 0.23 gz = 0.03 deg/s
mx = -91 my = -483 mz = -478 mG
-0.200.410.870.18
Yaw, Pitch, Roll:
124.09, -29.93, 170.05
ax = 44.19 ay = -302.19 az = -1005.49 mg
gx = -0.10 gy = 0.36 gz = -0.05 deg/s
mx = -69 my = -472 mz = -471 mG
-0.10-0.090.83-0.54
Yaw, Pitch, Roll:
-186.66, -15.36, -114.67
ax = 42.48 ay = -305.11 az = -1008.97 mg
gx = -0.12 gy = 0.14 gz = 0.04 deg/s
mx = -85 my = -474 mz = -497 mG
-0.210.420.860.19
Yaw, Pitch, Roll:
122.11, -30.88, 170.19
ax = 41.20 ay = -301.39 az = -1010.62 mg
gx = -0.21 gy = 0.43 gz = -0.03 deg/s
mx = -96 my = -481 mz = -483 mG
-0.11-0.090.84-0.53
Yaw, Pitch, Roll:
-186.20, -16.45, -115.61
ax = 42.60 ay = -303.28 az = -1006.04 mg
gx = -0.02 gy = 0.25 gz = 0.08 deg/s
mx = -85 my = -474 mz = -470 mG
-0.190.390.880.19
Yaw, Pitch, Roll:
126.80, -28.78, 168.31
ax = 45.04 ay = -302.37 az = -1007.51 mg
gx = -0.20 gy = 0.28 gz = 0.06 deg/s
mx = -80 my = -486 mz = -489 mG
-0.11-0.110.83-0.53
Yaw, Pitch, Roll:
-184.33, -17.75, -115.75
ax = 45.10 ay = -302.80 az = -1007.93 mg
gx = -0.14 gy = 0.25 gz = -0.02 deg/s
mx = -82 my = -481 mz = -476 mG
-0.200.390.880.18
Yaw, Pitch, Roll:
125.85, -29.06, 169.68
ax = 44.25 ay = -305.48 az = -1007.39 mg
gx = -0.18 gy = 0.30 gz = 0.03 deg/s
mx = -93 my = -481 mz = -476 mG
-0.11-0.110.83-0.53
Yaw, Pitch, Roll:
-184.56, -17.01, -115.13
ax = 41.38 ay = -305.11 az = -1006.71 mg
gx = -0.21 gy = 0.29 gz = 0.01 deg/s
mx = -78 my = -481 mz = -463 mG
-0.200.400.880.17
Yaw, Pitch, Roll:
124.80, -28.98, 170.71
ax = 42.24 ay = -301.03 az = -1010.74 mg
gx = -0.23 gy = 0.54 gz = 0.03 deg/s
mx = -78 my = -481 mz = -490 mG
-0.10-0.080.83-0.55
Yaw, Pitch, Roll:
-186.81, -14.53, -113.13
ax = 43.82 ay = -303.59 az = -1009.28 mg
gx = -0.13 gy = 0.31 gz = -0.04 deg/s
mx = -85 my = -477 mz = -483 mG
-0.220.430.860.18
Yaw, Pitch, Roll:
119.90, -31.47, 172.18
ax = 42.36 ay = -302.61 az = -1008.12 mg
gx = -0.16 gy = 0.31 gz = 0.02 deg/s
mx = -80 my = -490 mz = -464 mG
-0.10-0.070.84-0.53
Yaw, Pitch, Roll:
-187.59, -14.18, -115.61
ax = 42.79 ay = -301.39 az = -1007.75 mg
gx = -0.15 gy = 0.13 gz = -0.02 deg/s
mx = -80 my = -472 mz = -478 mG
-0.200.410.870.19
Yaw, Pitch, Roll:
123.40, -30.35, 168.94
ax = 42.60 ay = -301.21 az = -1006.04 mg
gx = -0.18 gy = 0.20 gz = 0.18 deg/s
mx = -82 my = -481 mz = -487 mG
-0.12-0.100.84-0.53
Yaw, Pitch, Roll:
-185.76, -17.32, -116.07
```

moving from positive to negative values without any sense.

biccius, 2020-12-07:
Do you have a code snippet to simulate it?

fabioetec, 2020-12-07:
> Do you have a code snippet to simulate it?

Sure! On line 10 of this file https://github.com/Xinyuan-LilyGO/LilyGo-T-Wristband/blob/master/examples/T-Wristband-MPU9250/sensor.h change:

`#define SerialDebugMPU9250 0`

with

`#define SerialDebugMPU9250 true`

then open serial monitor and, with the button on the device, go to the page where you see accelerometer values (green text on black background). On the serial monitor, you will see the output printed by this code (lines 185-192 same sensor.h file, you can also remove comment on line with header "Yaw, Pitch, Roll: ")

 ```
   if (SerialDebugMPU9250) {
      // Serial.println("Yaw, Pitch, Roll: ");
      Serial.print(IMU.yaw, 2);
      Serial.print(", ");
      Serial.print(IMU.pitch, 2);
      Serial.print(", ");
      Serial.println(IMU.roll, 2);
    }
```

Without moving the device I should get almost the same number for yaw, pitch and roll, instead I get differents values at every loop.

For any other question don't hesitate to ask!

fabioetec, 2020-12-26:
Any news??

biccius, 2021-02-08:
Sorry, but i don't have MPU9250
With LSM9DS1 i'm able to get valid pitch and roll values using this snippet of code

`void LilyGo::getCurrentOrientation()
{
	this->update_imu();

	x = imu.calcAccel(imu.ax);
	y = imu.calcAccel(imu.ay);
	z = imu.calcAccel(imu.az);

	pitch = atan2(x, sqrt(y * y) + (z * z));
	roll = atan2(y, sqrt(x * x) + (z * z));
	pitch *= 180.0 / M_PI;
	roll *= 180.0 / M_PI;
`

Hope it can help

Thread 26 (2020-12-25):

max30102 does not fit

alexisicte, 2020-12-25:
Hello, first of all many thanks for such a hardware. I am trying to fit max30102 sensor in the enclosure but the fpc line is too short and/or the battery is too thick in order to have a perfectly fit inside the enclosure.

Am i missing something here or this is the case?  I am following the spots on the bottom enclosure in order to fit the sensor but it does not fit.

Am i trying to install the sensor in a wrong way?

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

alexisicte, 2021-07-14:
Buy the extended sensor if you want to fit with the bigger battery.

Closed 2021-07-14.

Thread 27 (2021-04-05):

Flashing error with T-Wristband-20200104.bin

michelepagot, 2021-04-05:
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

16:58:41: can't open file './RESOURCE/IDLE_S.bmp' (error 3: the system cannot find the path specified.)
16:58:41: Failed to load image from file "./RESOURCE/IDLE_S.bmp".

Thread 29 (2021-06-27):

Time out issue

HoopmanJ20, 2021-06-27:
I have bought three of these boards and every time I have an issue with them that goes like this:

Connecting........_____....._____....._____....._____....._____....._____.....____An error occurred while uploading the sketch
_

A fatal error occurred: Failed to connect to ESP32: Timed out waiting for packet header

 I have installed the driver and I am not sure what's going on. Any suggestions would be greatly appreciated!

HoopmanJ20, 2022-02-16:
Found a fix: it wasnt the esp32 version, was the nrf52832 version

Closed 2022-09-05.

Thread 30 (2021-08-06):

wrong pin. IMU, WOM, MPU9250

ErickRBTK, 2021-08-06:
did anyone else notice this?
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

liangyingy, 2022-09-05:
that's right.

Closed 2022-09-05.

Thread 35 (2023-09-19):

Problem to interface with SDCARD.  Connecting an SD card to the T-Wristband using the Flash Tool Board

fabiopellini, 2023-09-19:
Connect an board ESP32  with  sdcard module is  ok: library SD, SPIClass spi = SPIClass(VSPI); with pin
CLK 14
MISO 12
MOSI 13
CS 15
But is NOK  with the ToolBoard

fabiopellini, 2023-09-19:
To complete description, sketch and test we have done:
[progetto  BRIC-error.pdf](https://github.com/Xinyuan-LilyGO/T-Wristband/files/12666947/progetto.BRIC-error.pdf)

fabiopellini, 2023-09-21:
Upload the  sketch without sdcard module,, and using
CLK 14
MISO 2
MOSI 13
CS 15

fabiopellini, 2023-09-21:
So now read SD, but why the pin 2 have that problem in upload?

Closed 2023-09-21.

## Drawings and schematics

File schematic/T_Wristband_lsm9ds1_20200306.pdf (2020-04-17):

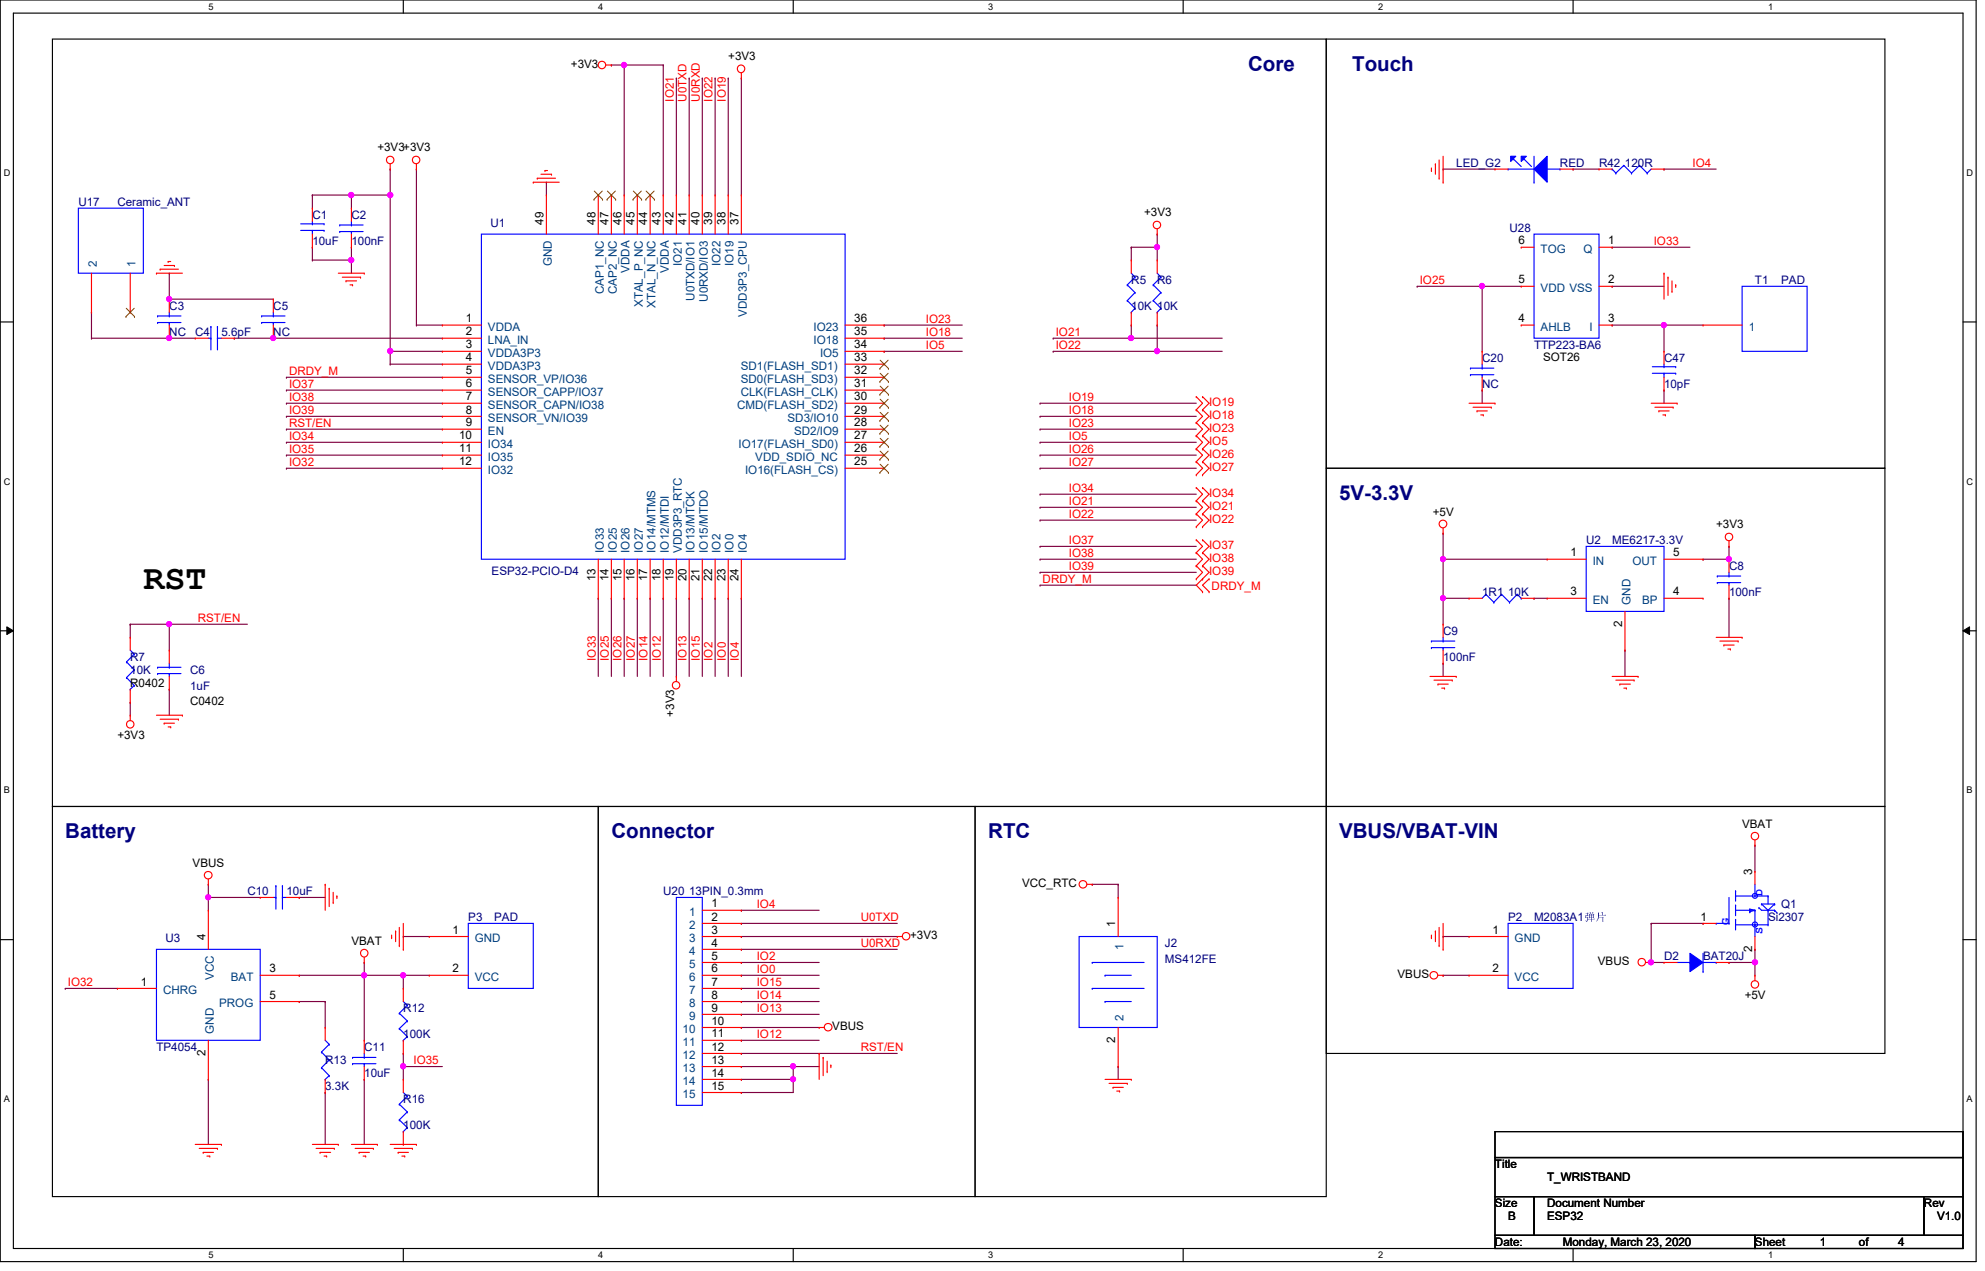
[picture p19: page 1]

# 0.96_IPS

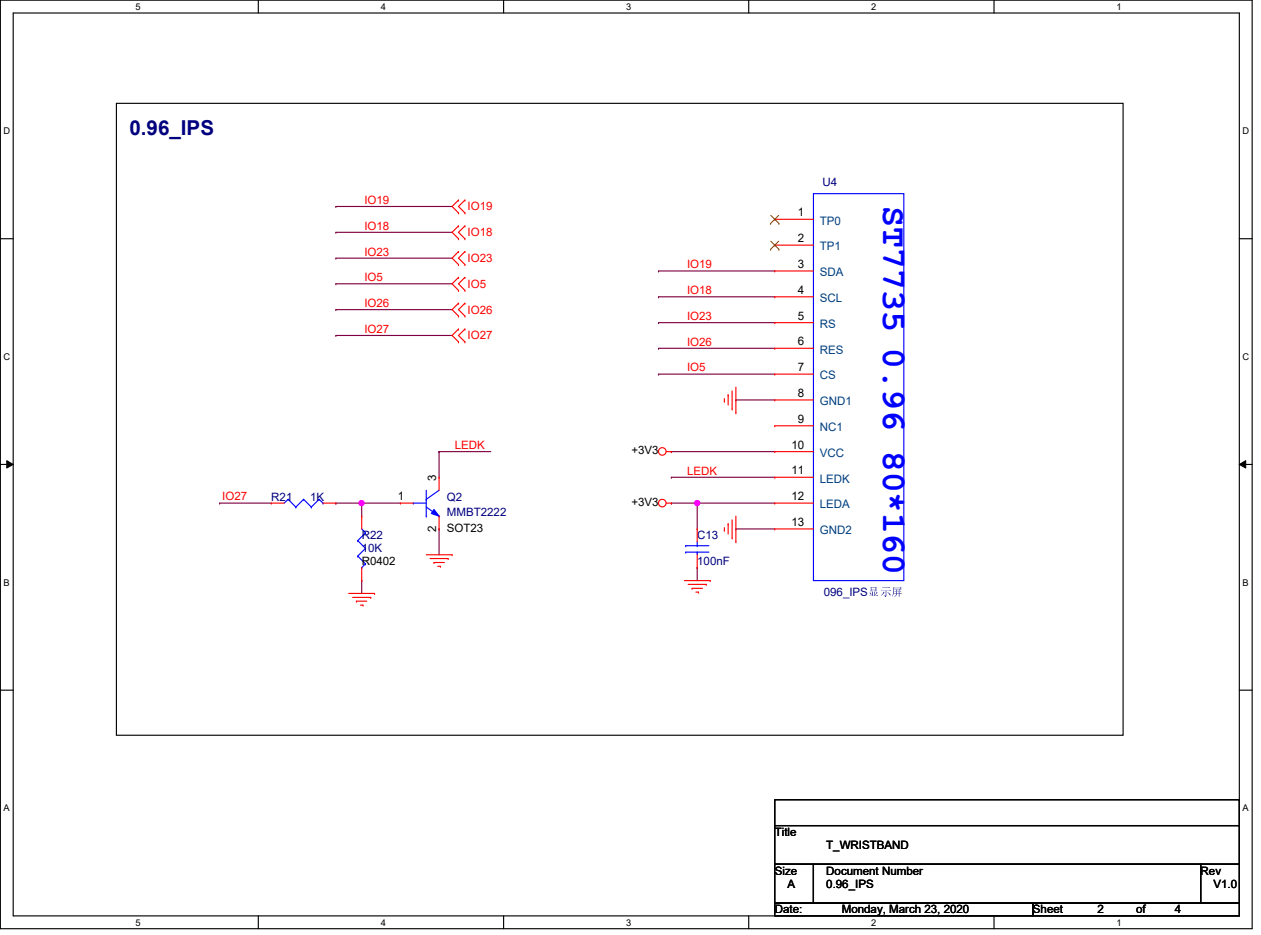
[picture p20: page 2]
LEDK; Title; Size; Document Number; Rev; Date:; Sheet; 0.96_IPS; T_WRISTBAND; Monday, March 23, 2020; 096_IPS显显显; SDA 3; SCL 4; RES 6; GND1 8; VCC 10; LEDK 11; LEDA 12; GND2 13; Q2 MMBT2222 SOT23

# RTC

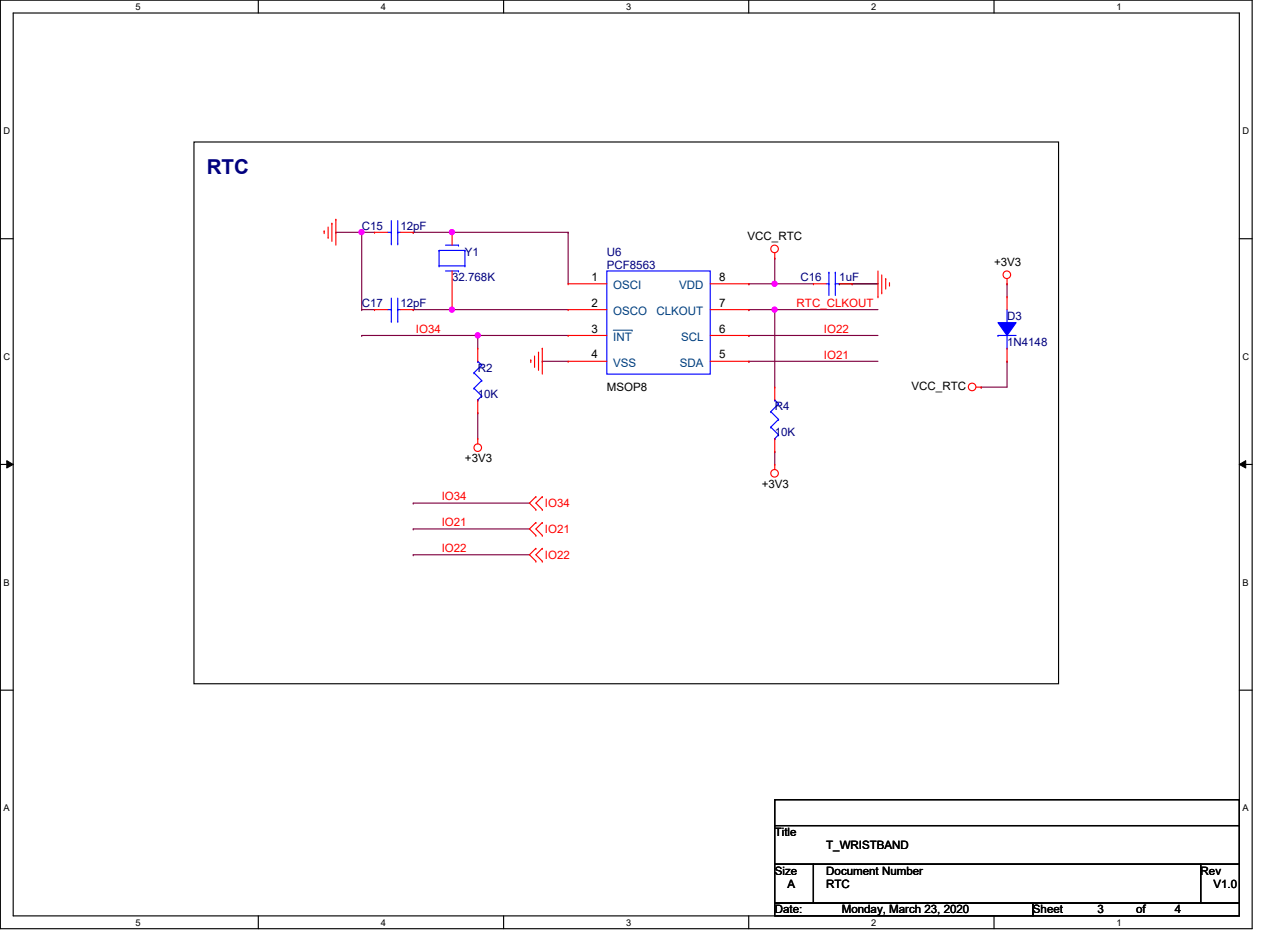
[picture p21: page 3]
RTC_CLKOUT; VCC_RTC; Title; RTC; T_WRISTBAND; Monday, March 23, 2020; U6 PCF8563; MSOP8; OSCI 1; OSCO 2; INT 3; VSS 4; SDA; SCL; CLKOUT; VDD

# accelerometer:加加加加 gyroscope：陀陀陀

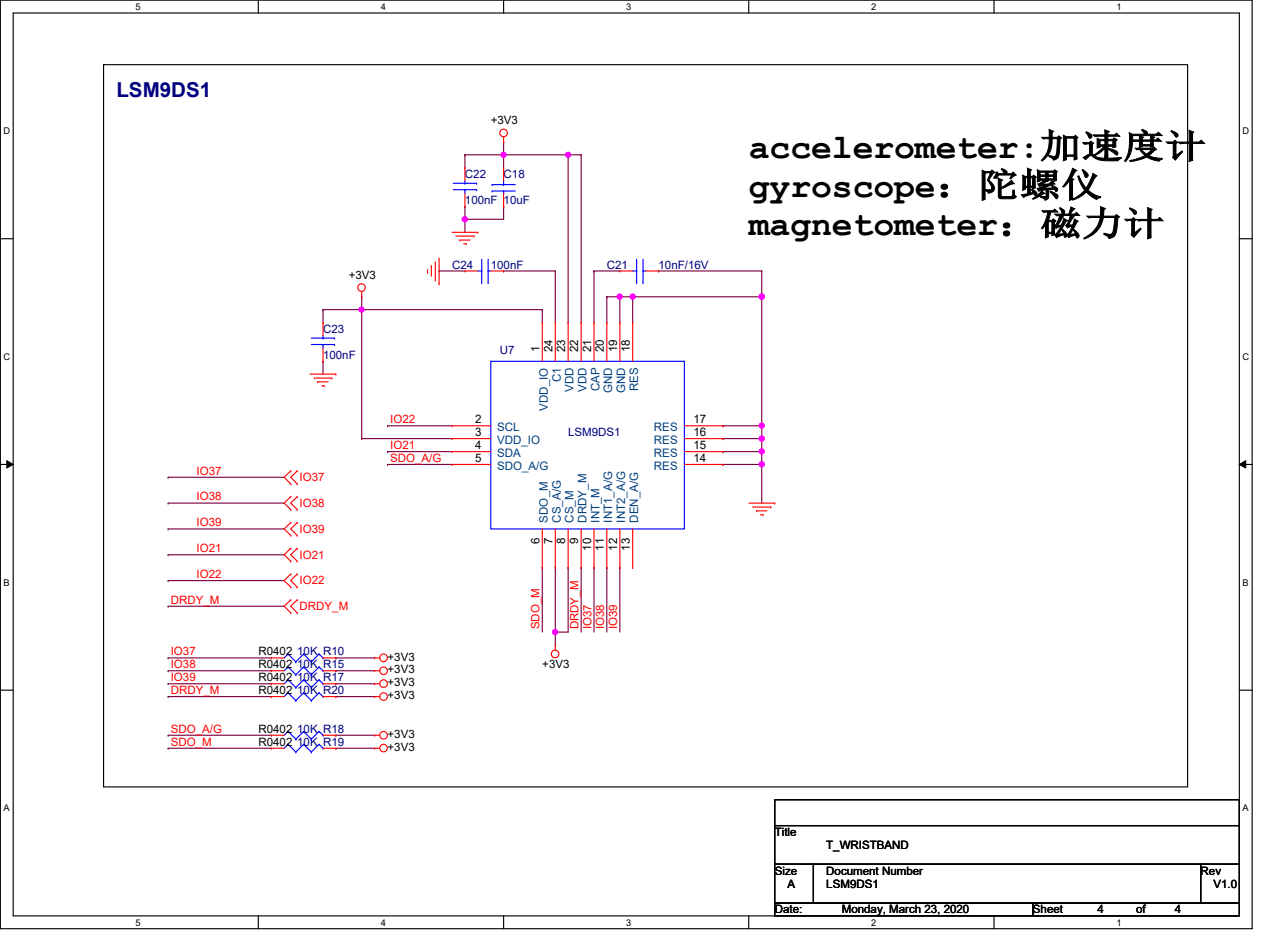
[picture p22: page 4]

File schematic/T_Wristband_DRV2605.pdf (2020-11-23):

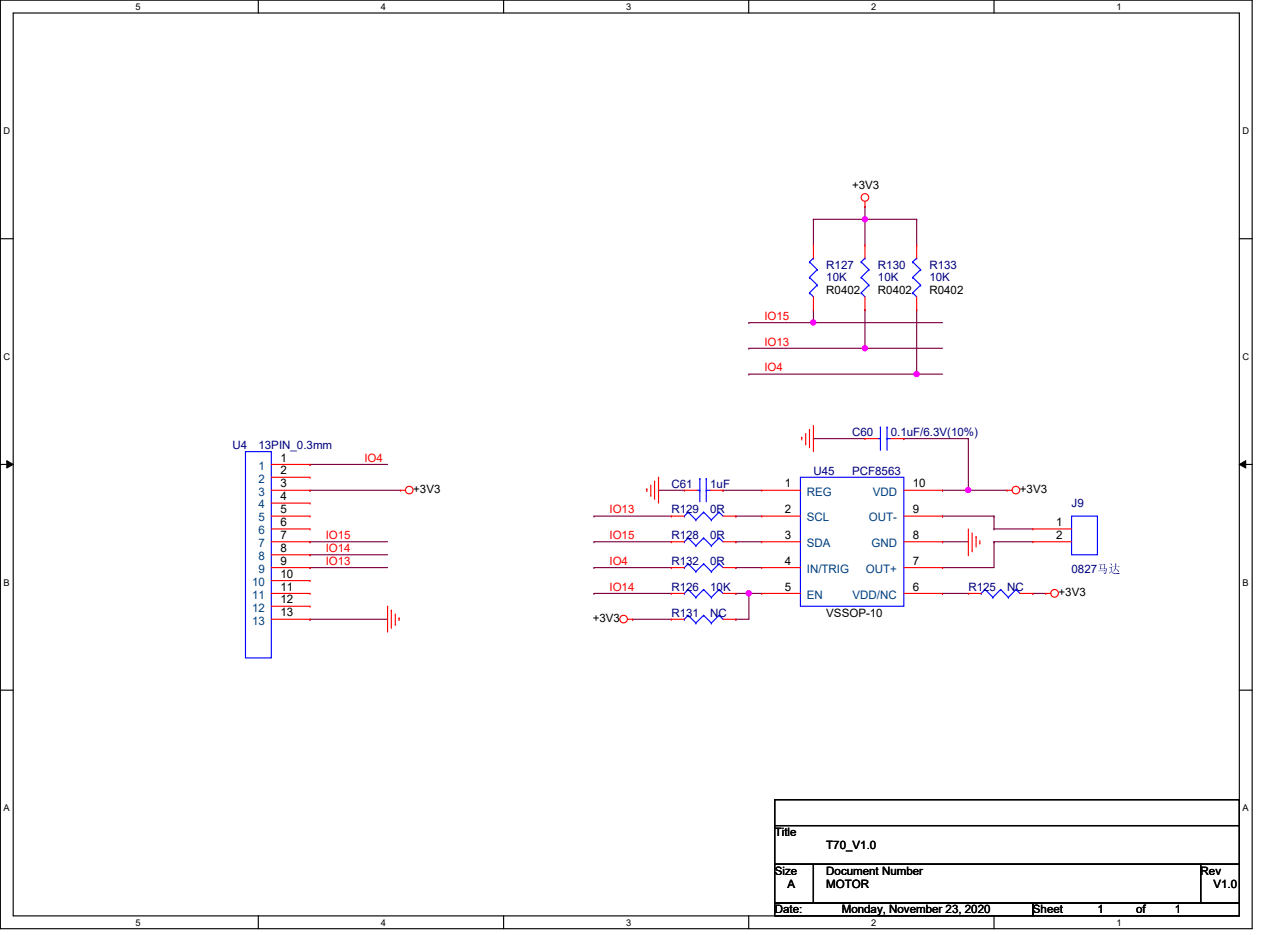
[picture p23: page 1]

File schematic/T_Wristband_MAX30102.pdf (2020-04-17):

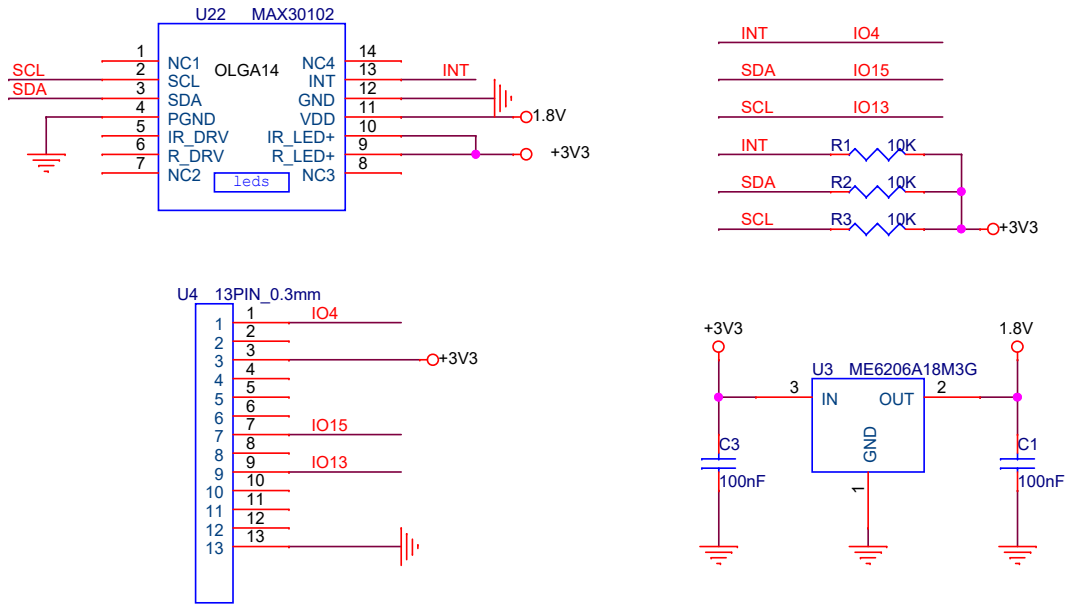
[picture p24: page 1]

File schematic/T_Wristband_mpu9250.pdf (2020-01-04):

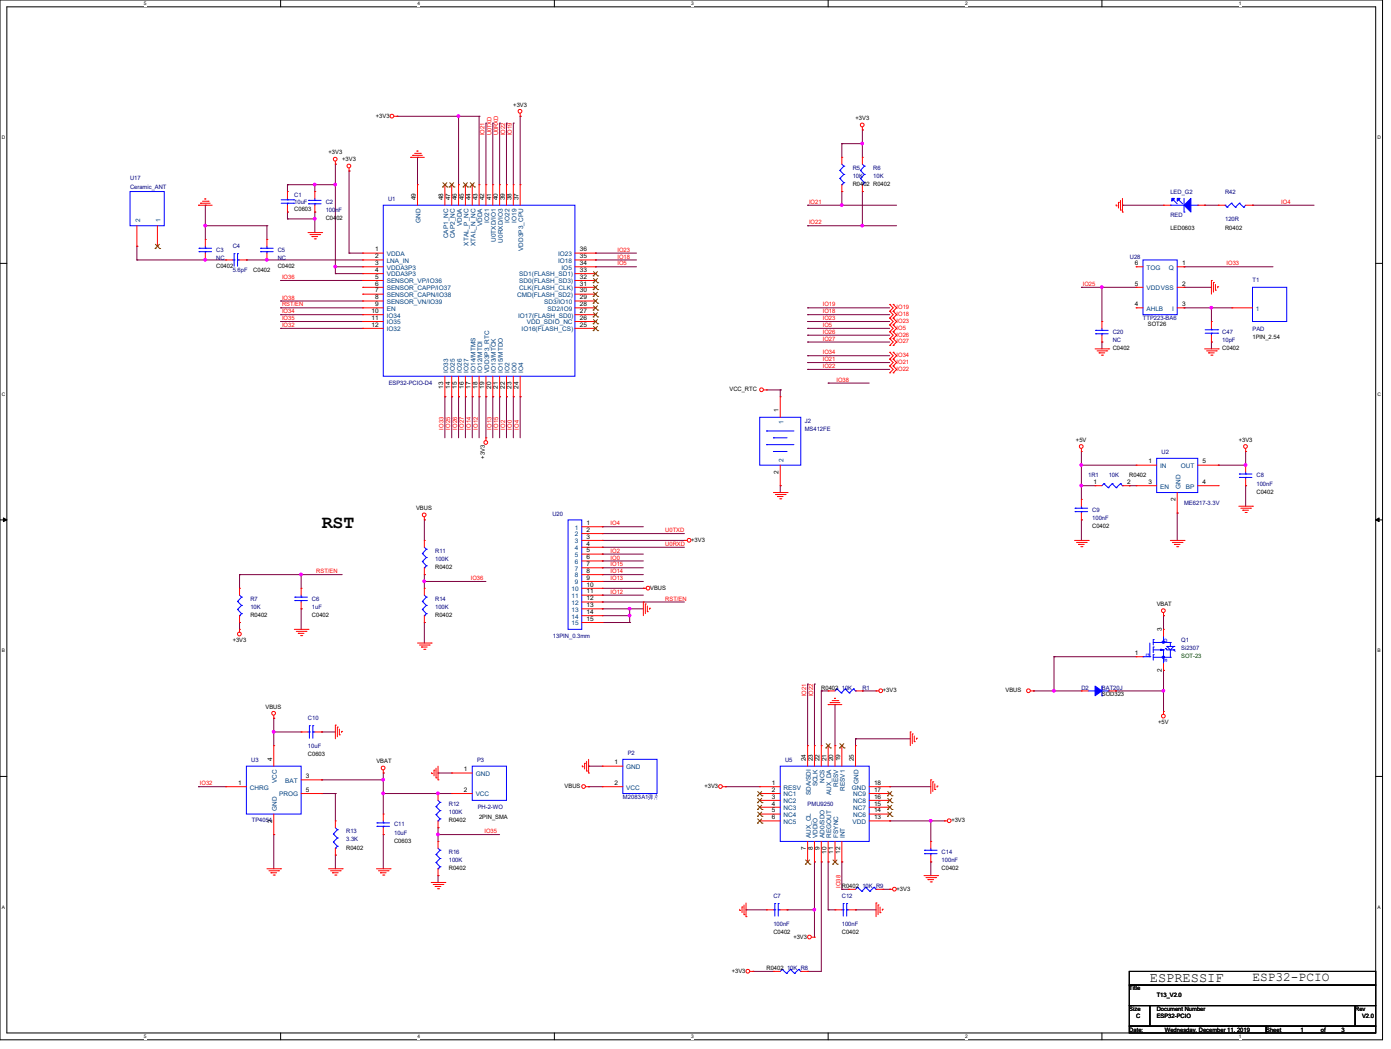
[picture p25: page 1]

5

4

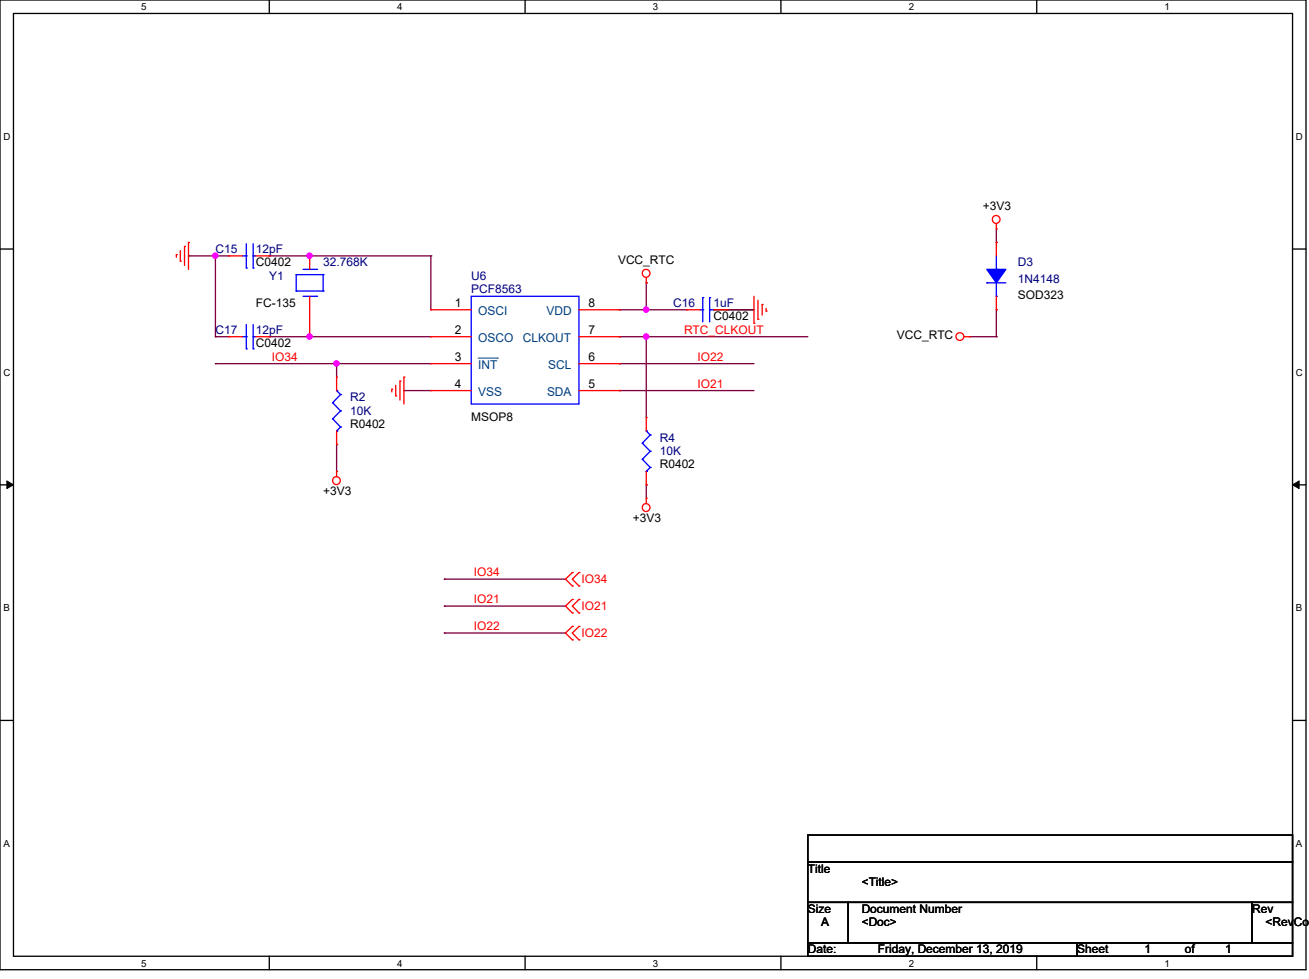
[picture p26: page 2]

55

44

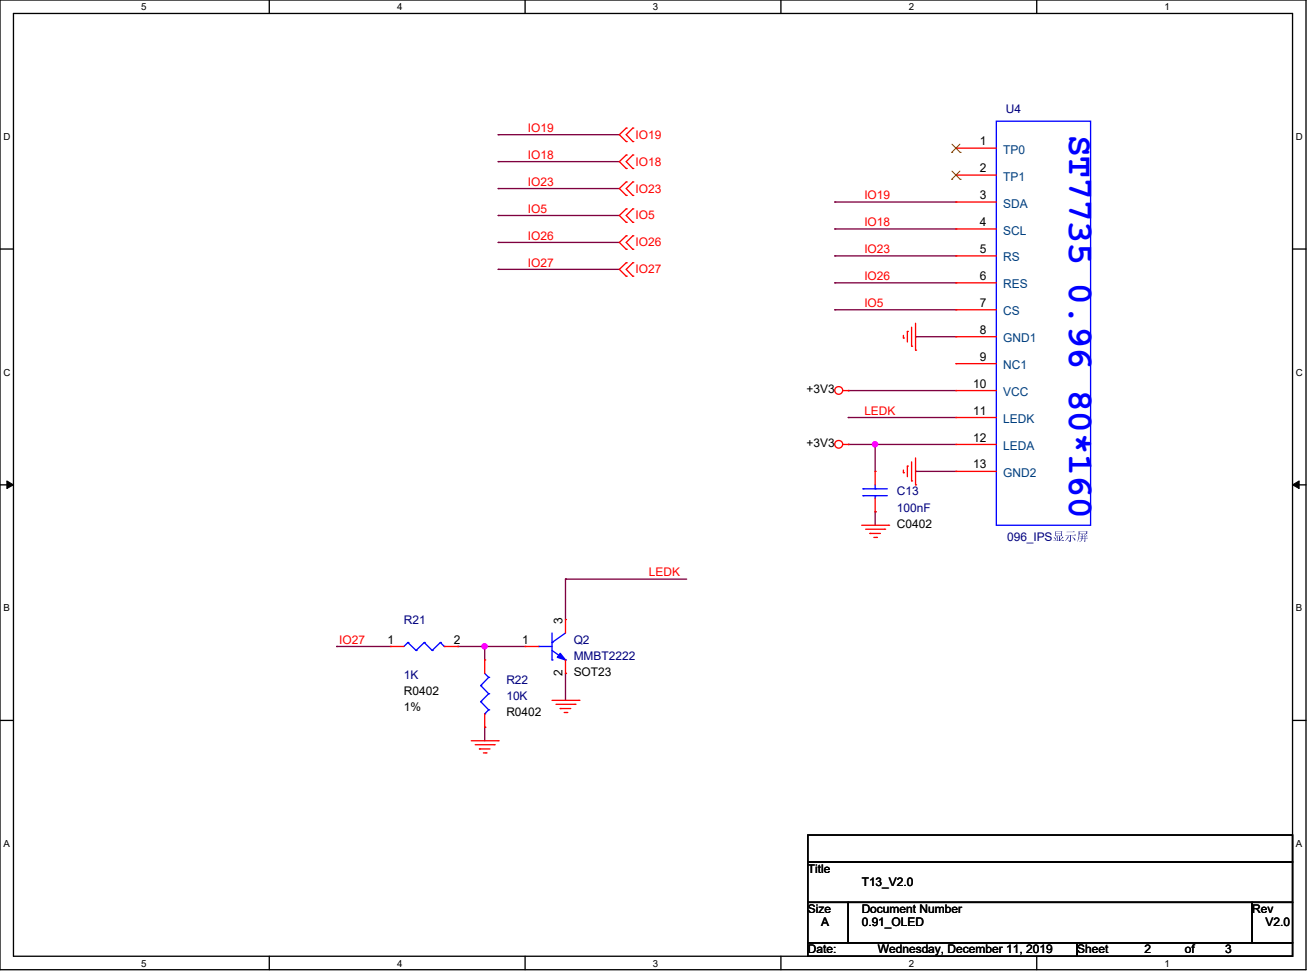
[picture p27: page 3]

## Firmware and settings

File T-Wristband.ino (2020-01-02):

#include <pcf8563.h>
#include <TFT_eSPI.h> // Graphics and font library for ST7735 driver chip
#include <SPI.h>
#include <Wire.h>
#include <WiFi.h>
#include "sensor.h"
#include "esp_adc_cal.h"
#include "ttgo.h"

// #define FACTORY_HW_TEST     //! Test RTC and WiFi scan when enabled
#define ARDUINO_OTA_UPDATE      //! Enable this line OTA update


#ifdef ARDUINO_OTA_UPDATE
#include <ESPmDNS.h>
#include <WiFiUdp.h>
#include <ArduinoOTA.h>

const char *ssid = "YOU_WIFI_SSID";
const char *password = "YOU_WIFI_PASSWORD";
#endif


#define TP_PIN_PIN          33
#define I2C_SDA_PIN         21
#define I2C_SCL_PIN         22
#define IMU_INT_PIN         4
#define RTC_INT_PIN         34
#define BATT_ADC_PIN        35
#define VBUS_PIN            36
#define TP_PWR_PIN          25
#define LED_PIN             4

extern MPU9250 IMU;

TFT_eSPI tft = TFT_eSPI();  // Invoke library, pins defined in User_Setup.h
PCF8563_Class rtc;

char buff[256];
bool rtcIrq = false;
bool initial = 1;
bool otaStart = false;

uint8_t func_select = 0;
uint8_t omm = 99;
uint8_t xcolon = 0;
uint32_t targetTime = 0;       // for next 1 second timeout
uint32_t colour = 0;
int vref = 1100;


uint8_t hh, mm, ss ;


void scanI2Cdevice(void)
{
    uint8_t err, addr;
    int nDevices = 0;
    for (addr = 1; addr < 127; addr++) {
        Wire.beginTransmission(addr);
        err = Wire.endTransmission();
        if (err == 0) {
            Serial.print("I2C device found at address 0x");
            if (addr < 16)
                Serial.print("0");
            Serial.print(addr, HEX);
            Serial.println(" !");
            nDevices++;
        } else if (err == 4) {
            Serial.print("Unknow error at address 0x");
            if (addr < 16)
                Serial.print("0");
            Serial.println(addr, HEX);
        }
    }
    if (nDevices == 0)
        Serial.println("No I2C devices found\n");
    else
        Serial.println("Done\n");
}


void wifi_scan()
{
    tft.setTextColor(TFT_GREEN, TFT_BLACK);
    tft.fillScreen(TFT_BLACK);
    tft.setTextDatum(MC_DATUM);
    tft.setTextSize(1);

    tft.drawString("Scan Network", tft.width() / 2, tft.height() / 2);

    WiFi.mode(WIFI_STA);
    WiFi.disconnect();
    delay(100);

    int16_t n = WiFi.scanNetworks();
    tft.fillScreen(TFT_BLACK);
    if (n == 0) {
        tft.drawString("no networks found", tft.width() / 2, tft.height() / 2);
    } else {
        tft.setTextDatum(TL_DATUM);
        tft.setCursor(0, 0);
        for (int i = 0; i < n; ++i) {
            sprintf(buff,
                    "[%d]:%s(%d)",
                    i + 1,
                    WiFi.SSID(i).c_str(),
                    WiFi.RSSI(i));
            Serial.println(buff);
            tft.println(buff);
        }
    }
    WiFi.mode(WIFI_OFF);
}


void drawProgressBar(uint16_t x0, uint16_t y0, uint16_t w, uint16_t h, uint8_t percentage, uint16_t frameColor, uint16_t barColor)
{
    if (percentage == 0) {
        tft.fillRoundRect(x0, y0, w, h, 3, TFT_BLACK);
    }
    uint8_t margin = 2;
    uint16_t barHeight = h - 2 * margin;
    uint16_t barWidth = w - 2 * margin;
    tft.drawRoundRect(x0, y0, w, h, 3, frameColor);
    tft.fillRect(x0 + margin, y0 + margin, barWidth * percentage / 100.0, barHeight, barColor);
}


void factoryTest()
{
    scanI2Cdevice();
    delay(2000);

    tft.fillScreen(TFT_BLACK);
    tft.drawString("RTC Interrupt self test", 0, 0);

    int yy = 2019, mm = 5, dd = 15, h = 2, m = 10, s = 0;
    rtc.begin(Wire);
    rtc.setDateTime(yy, mm, dd, h, m, s);
    delay(500);
    RTC_Date dt = rtc.getDateTime();
    if (dt.year != yy || dt.month != mm || dt.day != dd || dt.hour != h || dt.minute != m) {
        tft.setTextColor(TFT_RED, TFT_BLACK);
        tft.fillScreen(TFT_BLACK);
        tft.drawString("Write DateTime FAIL", 0, 0);
    } else {
        tft.setTextColor(TFT_GREEN, TFT_BLACK);
        tft.fillScreen(TFT_BLACK);
        tft.drawString("Write DateTime PASS", 0, 0);
    }

    delay(2000);

    //! RTC Interrupt Test
    pinMode(RTC_INT_PIN, INPUT_PULLUP); //need change to rtc_pin
    attachInterrupt(RTC_INT_PIN, [] {
        rtcIrq = 1;
    }, FALLING);

    rtc.disableAlarm();

    rtc.setDateTime(2019, 4, 7, 9, 5, 57);

    rtc.setAlarmByMinutes(6);

    rtc.enableAlarm();

    for (;;) {
        snprintf(buff, sizeof(buff), "%s", rtc.formatDateTime());
        Serial.print("\t");
        Serial.println(buff);
        tft.fillScreen(TFT_BLACK);
        tft.drawString(buff, 0, 0);

        if (rtcIrq) {
            rtcIrq = 0;
            detachInterrupt(RTC_INT_PIN);
            rtc.resetAlarm();
            break;
        }
        delay(1000);
    }
    tft.setTextColor(TFT_GREEN, TFT_BLACK);
    tft.fillScreen(TFT_BLACK);
    tft.drawString("RTC Interrupt PASS", 0, 0);
    delay(2000);

    wifi_scan();
    delay(2000);
}

void setupWiFi()
{
#ifdef ARDUINO_OTA_UPDATE
    WiFi.mode(WIFI_STA);
    WiFi.begin(ssid, password);
    while (WiFi.waitForConnectResult() != WL_CONNECTED) {
        Serial.println("Connection Failed! Rebooting...");
        delay(5000);
        ESP.restart();
    }

    Serial.println("Ready");
    Serial.print("IP address: ");
    Serial.println(WiFi.localIP());
#endif
}

void setupOTA()
{
#ifdef ARDUINO_OTA_UPDATE
    // Port defaults to 3232
    // ArduinoOTA.setPort(3232);

    // Hostname defaults to esp3232-[MAC]
    ArduinoOTA.setHostname("T-Wristband");

    // No authentication by default
    // ArduinoOTA.setPassword("admin");

    // Password can be set with it's md5 value as well
    // MD5(admin) = 21232f297a57a5a743894a0e4a801fc3
    // ArduinoOTA.setPasswordHash("21232f297a57a5a743894a0e4a801fc3");

    ArduinoOTA.onStart([]() {
        String type;
        if (ArduinoOTA.getCommand() == U_FLASH)
            type = "sketch";
        else // U_SPIFFS
            type = "filesystem";

        // NOTE: if updating SPIFFS this would be the place to unmount SPIFFS using SPIFFS.end()
        Serial.println("Start updating " + type);
        otaStart = true;
        tft.fillScreen(TFT_BLACK);
        tft.drawString("Updating...", tft.width() / 2 - 20, 55 );
    })
    .onEnd([]() {
        Serial.println("\nEnd");
        delay(500);
    })
    .onProgress([](unsigned int progress, unsigned int total) {
        // Serial.printf("Progress: %u%%\r", (progress / (total / 100)));
        int percentage = (progress / (total / 100));
        tft.setTextDatum(TC_DATUM);
        tft.setTextPadding(tft.textWidth(" 888% "));
        tft.drawString(String(percentage) + "%", 145, 35);
        drawProgressBar(10, 30, 120, 15, percentage, TFT_WHITE, TFT_BLUE);
    })
    .onError([](ota_error_t error) {
        Serial.printf("Error[%u]: ", error);
        if (error == OTA_AUTH_ERROR) Serial.println("Auth Failed");
        else if (error == OTA_BEGIN_ERROR) Serial.println("Begin Failed");
        else if (error == OTA_CONNECT_ERROR) Serial.println("Connect Failed");
        else if (error == OTA_RECEIVE_ERROR) Serial.println("Receive Failed");
        else if (error == OTA_END_ERROR) Serial.println("End Failed");

        tft.fillScreen(TFT_BLACK);
        tft.drawString("Update Failed", tft.width() / 2 - 20, 55 );
        delay(3000);
        otaStart = false;
        initial = 1;
        targetTime = millis() + 1000;
        tft.fillScreen(TFT_BLACK);
        tft.setTextDatum(TL_DATUM);
        omm = 99;
    });

    ArduinoOTA.begin();
#endif
}


void setupADC()
{
    esp_adc_cal_characteristics_t adc_chars;
    esp_adc_cal_value_t val_type = esp_adc_cal_characterize((adc_unit_t)ADC_UNIT_1, (adc_atten_t)ADC1_CHANNEL_6, (adc_bits_width_t)ADC_WIDTH_BIT_12, 1100, &adc_chars);
    //Check type of calibration value used to characterize ADC
    if (val_type == ESP_ADC_CAL_VAL_EFUSE_VREF) {
        Serial.printf("eFuse Vref:%u mV", adc_chars.vref);
        vref = adc_chars.vref;
    } else if (val_type == ESP_ADC_CAL_VAL_EFUSE_TP) {
        Serial.printf("Two Point --> coeff_a:%umV coeff_b:%umV\n", adc_chars.coeff_a, adc_chars.coeff_b);
    } else {
        Serial.println("Default Vref: 1100mV");
    }
}

void setupRTC()
{
    rtc.begin(Wire);
    //Check if the RTC clock matches, if not, use compile time
    rtc.check();

    RTC_Date datetime = rtc.getDateTime();
    hh = datetime.hour;
    mm = datetime.minute;
    ss = datetime.second;
}

void setup(void)
{
    Serial.begin(115200);

    tft.init();
    tft.setRotation(1);
    tft.setSwapBytes(true);
    tft.pushImage(0, 0,  160, 80, ttgo);
    tft.setSwapBytes(false);

    Wire.begin(I2C_SDA_PIN, I2C_SCL_PIN);
    Wire.setClock(400000);

#ifdef FACTORY_HW_TEST
    factoryTest();
#endif

    setupRTC();

    setupMPU9250();

    setupADC();

    setupWiFi();

    setupOTA();

    tft.fillScreen(TFT_BLACK);

    tft.setTextColor(TFT_YELLOW, TFT_BLACK); // Note: the new fonts do not draw the background colour

    targetTime = millis() + 1000;

    pinMode(TP_PIN_PIN, INPUT);
    //! Must be set to pull-up output mode in order to wake up in deep sleep mode
    pinMode(TP_PWR_PIN, PULLUP);
    digitalWrite(TP_PWR_PIN, HIGH);

    pinMode(LED_PIN, INPUT);
}

String getVoltage()
{
    uint16_t v = analogRead(BATT_ADC_PIN);
    float battery_voltage = ((float)v / 4095.0) * 2.0 * 3.3 * (vref / 1000.0);
    return String(battery_voltage) + "V";
}

void RTC_Show()
{
    if (targetTime < millis()) {
        RTC_Date datetime = rtc.getDateTime();
        hh = datetime.hour;
        mm = datetime.minute;
        ss = datetime.second;
        // Serial.printf("hh:%d mm:%d ss:%d\n", hh, mm, ss);
        targetTime = millis() + 1000;
        if (ss == 0 || initial) {
            initial = 0;
            tft.setTextColor(TFT_GREEN, TFT_BLACK);
            tft.setCursor (8, 60);
            tft.print(__DATE__); // This uses the standard ADAFruit small font
        }

        tft.setTextColor(TFT_BLUE, TFT_BLACK);
        tft.drawCentreString(getVoltage(), 120, 60, 1); // Next size up font 2


        // Update digital time
        uint8_t xpos = 6;
        uint8_t ypos = 0;
        if (omm != mm) { // Only redraw every minute to minimise flicker
            // Uncomment ONE of the next 2 lines, using the ghost image demonstrates text overlay as time is drawn over it
            tft.setTextColor(0x39C4, TFT_BLACK);  // Leave a 7 segment ghost image, comment out next line!
            //tft.setTextColor(TFT_BLACK, TFT_BLACK); // Set font colour to black to wipe image
            // Font 7 is to show a pseudo 7 segment display.
            // Font 7 only contains characters [space] 0 1 2 3 4 5 6 7 8 9 0 : .
            tft.drawString("88:88", xpos, ypos, 7); // Overwrite the text to clear it
            tft.setTextColor(0xFBE0, TFT_BLACK); // Orange
            omm = mm;

            if (hh < 10) xpos += tft.drawChar('0', xpos, ypos, 7);
            xpos += tft.drawNumber(hh, xpos, ypos, 7);
            xcolon = xpos;
            xpos += tft.drawChar(':', xpos, ypos, 7);
            if (mm < 10) xpos += tft.drawChar('0', xpos, ypos, 7);
            tft.drawNumber(mm, xpos, ypos, 7);
        }

        if (ss % 2) { // Flash the colon
            tft.setTextColor(0x39C4, TFT_BLACK);
            xpos += tft.drawChar(':', xcolon, ypos, 7);
            tft.setTextColor(0xFBE0, TFT_BLACK);
        } else {
            tft.drawChar(':', xcolon, ypos, 7);
        }
    }
}

void IMU_Show()
{
    tft.setTextColor(TFT_GREEN, TFT_BLACK);
    tft.fillScreen(TFT_BLACK);
    tft.setTextDatum(TL_DATUM);
    readMPU9250();
    snprintf(buff, sizeof(buff), "--  ACC  GYR   MAG");
    tft.drawString(buff, 0, 0);
    snprintf(buff, sizeof(buff), "x %.2f  %.2f  %.2f", (int)1000 * IMU.ax, IMU.gx, IMU.mx);
    tft.drawString(buff, 0, 16);
    snprintf(buff, sizeof(buff), "y %.2f  %.2f  %.2f", (int)1000 * IMU.ay, IMU.gy, IMU.my);
    tft.drawString(buff, 0, 32);
    snprintf(buff, sizeof(buff), "z %.2f  %.2f  %.2f", (int)1000 * IMU.az, IMU.gz, IMU.mz);
    tft.drawString(buff, 0, 48);
    delay(200);
}




void loop()
{
#ifdef ARDUINO_OTA_UPDATE
    ArduinoOTA.handle();
#endif

    //! If OTA starts, skip the following operation
    if (otaStart)
        return;

    if (digitalRead(TP_PIN_PIN) == HIGH) {
        initial = 1;
        targetTime = millis() + 1000;
        tft.fillScreen(TFT_BLACK);
        omm = 99;
        func_select = func_select + 1 > 2 ? 0 : func_select + 1;
        digitalWrite(LED_PIN, HIGH);
        delay(100);
        digitalWrite(LED_PIN, LOW);
    }
    switch (func_select) {
    case 0:
        RTC_Show();
        break;
    case 1:
        IMU_Show();
        break;
    case 2:
        tft.setTextColor(TFT_GREEN, TFT_BLACK);
        tft.setTextDatum(MC_DATUM);
        tft.drawString("Press again to wake up",  tft.width() / 2, tft.height() / 2 );
        IMU.setSleepEnabled(true);
        Serial.println("Go to Sleep");
        delay(3000);
        tft.writecommand(ST7735_SLPIN);
        tft.writecommand(ST7735_DISPOFF);
        esp_sleep_enable_ext1_wakeup(GPIO_SEL_33, ESP_EXT1_WAKEUP_ANY_HIGH);
        esp_deep_sleep_start();
        break;
    default:
        break;
    }
}

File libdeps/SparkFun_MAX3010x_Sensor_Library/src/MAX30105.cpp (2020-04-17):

/***************************************************
  This is a library written for the Maxim MAX30105 Optical Smoke Detector
  It should also work with the MAX30102. However, the MAX30102 does not have a Green LED.

  These sensors use I2C to communicate, as well as a single (optional)
  interrupt line that is not currently supported in this driver.

  Written by Peter Jansen and Nathan Seidle (SparkFun)
  BSD license, all text above must be included in any redistribution.
 *****************************************************/

#include "MAX30105.h"

// Status Registers
static const uint8_t MAX30105_INTSTAT1 =		0x00;
static const uint8_t MAX30105_INTSTAT2 =		0x01;
static const uint8_t MAX30105_INTENABLE1 =		0x02;
static const uint8_t MAX30105_INTENABLE2 =		0x03;

// FIFO Registers
static const uint8_t MAX30105_FIFOWRITEPTR = 	0x04;
static const uint8_t MAX30105_FIFOOVERFLOW = 	0x05;
static const uint8_t MAX30105_FIFOREADPTR = 	0x06;
static const uint8_t MAX30105_FIFODATA =		0x07;

// Configuration Registers
static const uint8_t MAX30105_FIFOCONFIG = 		0x08;
static const uint8_t MAX30105_MODECONFIG = 		0x09;
static const uint8_t MAX30105_PARTICLECONFIG = 	0x0A;    // Note, sometimes listed as "SPO2" config in datasheet (pg. 11)
static const uint8_t MAX30105_LED1_PULSEAMP = 	0x0C;
static const uint8_t MAX30105_LED2_PULSEAMP = 	0x0D;
static const uint8_t MAX30105_LED3_PULSEAMP = 	0x0E;
static const uint8_t MAX30105_LED_PROX_AMP = 	0x10;
static const uint8_t MAX30105_MULTILEDCONFIG1 = 0x11;
static const uint8_t MAX30105_MULTILEDCONFIG2 = 0x12;

// Die Temperature Registers
static const uint8_t MAX30105_DIETEMPINT = 		0x1F;
static const uint8_t MAX30105_DIETEMPFRAC = 	0x20;
static const uint8_t MAX30105_DIETEMPCONFIG = 	0x21;

// Proximity Function Registers
static const uint8_t MAX30105_PROXINTTHRESH = 	0x30;

// Part ID Registers
static const uint8_t MAX30105_REVISIONID = 		0xFE;
static const uint8_t MAX30105_PARTID = 			0xFF;    // Should always be 0x15. Identical to MAX30102.

// MAX30105 Commands
// Interrupt configuration (pg 13, 14)
static const uint8_t MAX30105_INT_A_FULL_MASK =		(byte)~0b10000000;
static const uint8_t MAX30105_INT_A_FULL_ENABLE = 	0x80;
static const uint8_t MAX30105_INT_A_FULL_DISABLE = 	0x00;

static const uint8_t MAX30105_INT_DATA_RDY_MASK = (byte)~0b01000000;
static const uint8_t MAX30105_INT_DATA_RDY_ENABLE =	0x40;
static const uint8_t MAX30105_INT_DATA_RDY_DISABLE = 0x00;

static const uint8_t MAX30105_INT_ALC_OVF_MASK = (byte)~0b00100000;
static const uint8_t MAX30105_INT_ALC_OVF_ENABLE = 	0x20;
static const uint8_t MAX30105_INT_ALC_OVF_DISABLE = 0x00;

static const uint8_t MAX30105_INT_PROX_INT_MASK = (byte)~0b00010000;
static const uint8_t MAX30105_INT_PROX_INT_ENABLE = 0x10;
static const uint8_t MAX30105_INT_PROX_INT_DISABLE = 0x00;

static const uint8_t MAX30105_INT_DIE_TEMP_RDY_MASK = (byte)~0b00000010;
static const uint8_t MAX30105_INT_DIE_TEMP_RDY_ENABLE = 0x02;
static const uint8_t MAX30105_INT_DIE_TEMP_RDY_DISABLE = 0x00;

static const uint8_t MAX30105_SAMPLEAVG_MASK =	(byte)~0b11100000;
static const uint8_t MAX30105_SAMPLEAVG_1 = 	0x00;
static const uint8_t MAX30105_SAMPLEAVG_2 = 	0x20;
static const uint8_t MAX30105_SAMPLEAVG_4 = 	0x40;
static const uint8_t MAX30105_SAMPLEAVG_8 = 	0x60;
static const uint8_t MAX30105_SAMPLEAVG_16 = 	0x80;
static const uint8_t MAX30105_SAMPLEAVG_32 = 	0xA0;

static const uint8_t MAX30105_ROLLOVER_MASK = 	0xEF;
static const uint8_t MAX30105_ROLLOVER_ENABLE = 0x10;
static const uint8_t MAX30105_ROLLOVER_DISABLE = 0x00;

static const uint8_t MAX30105_A_FULL_MASK = 	0xF0;

// Mode configuration commands (page 19)
static const uint8_t MAX30105_SHUTDOWN_MASK = 	0x7F;
static const uint8_t MAX30105_SHUTDOWN = 		0x80;
static const uint8_t MAX30105_WAKEUP = 			0x00;

static const uint8_t MAX30105_RESET_MASK = 		0xBF;
static const uint8_t MAX30105_RESET = 			0x40;

static const uint8_t MAX30105_MODE_MASK = 		0xF8;
static const uint8_t MAX30105_MODE_REDONLY = 	0x02;
static const uint8_t MAX30105_MODE_REDIRONLY = 	0x03;
static const uint8_t MAX30105_MODE_MULTILED = 	0x07;

// Particle sensing configuration commands (pgs 19-20)
static const uint8_t MAX30105_ADCRANGE_MASK = 	0x9F;
static const uint8_t MAX30105_ADCRANGE_2048 = 	0x00;
static const uint8_t MAX30105_ADCRANGE_4096 = 	0x20;
static const uint8_t MAX30105_ADCRANGE_8192 = 	0x40;
static const uint8_t MAX30105_ADCRANGE_16384 = 	0x60;

static const uint8_t MAX30105_SAMPLERATE_MASK = 0xE3;
static const uint8_t MAX30105_SAMPLERATE_50 = 	0x00;
static const uint8_t MAX30105_SAMPLERATE_100 = 	0x04;
static const uint8_t MAX30105_SAMPLERATE_200 = 	0x08;
static const uint8_t MAX30105_SAMPLERATE_400 = 	0x0C;
static const uint8_t MAX30105_SAMPLERATE_800 = 	0x10;
static const uint8_t MAX30105_SAMPLERATE_1000 = 0x14;
static const uint8_t MAX30105_SAMPLERATE_1600 = 0x18;
static const uint8_t MAX30105_SAMPLERATE_3200 = 0x1C;

static const uint8_t MAX30105_PULSEWIDTH_MASK = 0xFC;
static const uint8_t MAX30105_PULSEWIDTH_69 = 	0x00;
static const uint8_t MAX30105_PULSEWIDTH_118 = 	0x01;
static const uint8_t MAX30105_PULSEWIDTH_215 = 	0x02;
static const uint8_t MAX30105_PULSEWIDTH_411 = 	0x03;

//Multi-LED Mode configuration (pg 22)
static const uint8_t MAX30105_SLOT1_MASK = 		0xF8;
static const uint8_t MAX30105_SLOT2_MASK = 		0x8F;
static const uint8_t MAX30105_SLOT3_MASK = 		0xF8;
static const uint8_t MAX30105_SLOT4_MASK = 		0x8F;

static const uint8_t SLOT_NONE = 				0x00;
static const uint8_t SLOT_RED_LED = 			0x01;
static const uint8_t SLOT_IR_LED = 				0x02;
static const uint8_t SLOT_GREEN_LED = 			0x03;
static const uint8_t SLOT_NONE_PILOT = 			0x04;
static const uint8_t SLOT_RED_PILOT =			0x05;
static const uint8_t SLOT_IR_PILOT = 			0x06;
static const uint8_t SLOT_GREEN_PILOT = 		0x07;

static const uint8_t MAX_30105_EXPECTEDPARTID = 0x15;

MAX30105::MAX30105() {
  // Constructor
}

boolean MAX30105::begin(TwoWire &wirePort, uint32_t i2cSpeed, uint8_t i2caddr) {

  _i2cPort = &wirePort; //Grab which port the user wants us to use

  // _i2cPort->begin();
  // _i2cPort->setClock(i2cSpeed);

  _i2caddr = i2caddr;

  // Step 1: Initial Communication and Verification
  // Check that a MAX30105 is connected
  if (readPartID() != MAX_30105_EXPECTEDPARTID) {
    // Error -- Part ID read from MAX30105 does not match expected part ID.
    // This may mean there is a physical connectivity problem (broken wire, unpowered, etc).
    return false;
  }

  // Populate revision ID
  readRevisionID();
  
  return true;
}

//
// Configuration
//

//Begin Interrupt configuration
uint8_t MAX30105::getINT1(void) {
  return (readRegister8(_i2caddr, MAX30105_INTSTAT1));
}
uint8_t MAX30105::getINT2(void) {
  return (readRegister8(_i2caddr, MAX30105_INTSTAT2));
}

void MAX30105::enableAFULL(void) {
  bitMask(MAX30105_INTENABLE1, MAX30105_INT_A_FULL_MASK, MAX30105_INT_A_FULL_ENABLE);
}
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

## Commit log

2019-12-05 add schematic
2019-12-05 Add Touchpad power control
2019-12-06 Added Touchpad power control,OTA option
2020-01-04 Add WiFiManager and Update schematic,readme
2020-01-06 add charge indication
2020-04-17 Update Max3010x,LSM9DS1 Version Board examples and update readme
    [Configuring options.txt]
2020-04-23 fix deepsleep wake sensor invaild
    [T-Wristband-LSM9DS1.ino]
2020-06-20 Added lsm9ds1 power-down mode and add related description
2020-06-24 Add Dimensions file
    [Shell_size.dxf]
2020-11-18 Added Drv2605 driver
2020-11-21 Added max30208 fail restart
    [T-Wristband-MAX30208.ino]
